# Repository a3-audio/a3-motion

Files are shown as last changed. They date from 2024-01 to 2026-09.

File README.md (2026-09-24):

# A³ Motion

The 4-channel motion sampler: records movement trajectories on a touchscreen
sphere and plays them back in time with the beat, steering per-channel
position on [A³ Core](https://github.com/a3-audio/a3-core) over OSC.

**The device runs on a Raspberry Pi 5.** The Pi carries the touchscreen UI --
[a3-motion-ui](https://github.com/a3-audio/a3-motion-ui), wired in here as the
`ui` submodule -- while the panel's buttons, encoders and pots are handled by
an ESP32-S3 (`firmware/`, a PlatformIO project) over a binary poll frame. The
PCB design is in `hardware/`.

## Setting up a new installation
- flash the latest Raspberry Pi OS Lite image
- resize sd-card space with gparted to maximum size
- boot raspberry pi
- define keyboard layout
- add user aaa and set password
- perform sudo apt update && sudo apt upgrade
- perform sudo apt install lightdm vim i3-wm dmenu x11-xserver-utils git build-essentials cmake libserial-dev gpiod libgpiod-dev
- Sudo raspi-config > Interface Options
  - (+) SSH
  - (+) I2C
- Sudo raspi-config > System-Settings > Hostname
  - a3-motion-v02
- sudo vim /etc/hosts
  - make sure hostname is correct
- sudo groupadd autologin
- sudo usermod -aG autologin aaa
- sudo vim /etc/lightdm/lightdm.conf
```
[Seat:*]
xserver-command=X -nocursor
autologin-user=aaa
autologin-session=i3
```
- sudo systemctl set-default graphical.target
- sudo systemctl enable lightdm
- configure autostart at the end of ~/.config/i3/config
  - remove bar {} block
  - rotate display for portrait orientation
  - rotate mouse input coordinates
  - disable screen saver and screen power management
  - start motion controller ui
```
exec --no-startup-id xrandr -o right
exec --no-startup-id xinput set-prop "wch.cn USB2IIC_CTP_CONTROL" --type=float "Coordinate Transformation Matrix" 0 1 0 -1 0 1 0 0 1

exec --no-startup-id xset s off
exec --no-startup-id xset -dpms

exec sleep 1

exec /usr/bin/bash /home/aaa/a3-system/a3motion/a3MotioncontrollerUI/moc.sh --serial_device /dev/ttyACM0 --server_ip "192.168.43.50" --server_port 9000 --encoder_base_port 1337
```
- configure network: vim /etc/dhcpcd.conf
```
# Example static IP configuration:
interface eth0
static ip_address=192.168.43.52/24
static routers=192.168.43.1
static domain_name_servers=192.168.43.1 8.8.8.8
```
- git clone --recursive https://github.com/a3-audio/a3-motion.git
- build a3-motion-ui
  - see a3motion/ui/readme.md

----------------------------------
- set up kernel config (TODO: what was changed compared to stock installation?)
```
#gpu_mem=64
initramfs initramfs-linux.img followkernel
kernel=kernel8.img
arm_64bit=1
disable_overscan=1
dtparam=krnbt=on

#enable sound
dtparam=audio=on
#hdmi_drive=2

#enable vc4
dtoverlay=vc4-kms-v3d
max_framebuffers=2
disable_splash=1

display_rotate=2
```

## Branching in Git

Work happens on `main`; a version is an annotated tag, set in every A³
repository at once. **The reasoning, and the scheme it replaced, are written
once in the umbrella** — see *Where this fits* below.

## Where this fits

A³ is seven repositories and one system. **The structure, the workflow and the
versioning are described once, in the umbrella:**
[a3-audio/a3-system](https://github.com/a3-audio/a3-system#repositories-and-versioning).

The short of it: work happens on `main`, a version is an annotated tag, and
the same tag name is set in every repository at once — `v03.0` is the first.

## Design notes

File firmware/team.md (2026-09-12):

# A3 Motion – Firmware Team Reference

## Überblick

Die Firmware läuft auf einem **ESP32-S3-DevKitC-1-N16R8** (16 MB Flash, 8 MB OPI PSRAM) unter dem Arduino-Framework via PlatformIO.

Die Kommunikation mit dem Host (z. B. Raspberry Pi oder PC) findet über **USB-CDC** statt – der ESP erscheint dabei als `/dev/ttyACM0` oder `/dev/ttyACM1`. Es werden keine separaten Hardware-UART-Pins belegt. Das Protokoll ist **binär** (Byte-Frames) und ermöglicht Auslesen von Buttons, Encodern, Potis sowie LED-Steuerung.

---

## Projektstruktur

```
firmware/
├── boards/
│   └── esp32-s3-devkitc-1-n16r8.json   Lokale Board-Definition (16 MB/PSRAM + USB-CDC aktiv)
├── include/
│   ├── config.h             GPIO-Pins, Konstanten, LED-Matrix-Definition
│   ├── multiplexer_map.h    Button-/Encoder-/Poti-Mappings (MATRIX_BUTTONS, ENCODERS, POTIS)
│   ├── mux_io.h             MUX-Kanal-Selektion und digitale Lesefunktionen
│   ├── buttons.h            Bounce2-Debounce + 2-Bit-Zustandsverfolgung für alle Buttons
│   ├── encoder.h            Quadratur-Dekodierung, Delta-Puffer, Encoder-Schalter-Debounce
│   ├── potis.h              ADC-Lesefunktionen für alle Potis
│   ├── usart.h              Thin Wrapper um USB-CDC Serial
│   ├── protocol.h           Protokoll-Dispatcher (PING, GET_POTS, GET_ENCODERS, GET_BUTTONS)
│   └── a3_special.h         Easter-Egg-Deklaration
└── src/
    ├── main.cpp             Setup, Loop, Protokoll-Dispatch, Easter-Egg-Trigger
    ├── mux_io.cpp
    ├── buttons.cpp
    ├── encoder.cpp
    ├── potis.cpp
    ├── usart.cpp
    ├── protocol.cpp
    └── a3_special.cpp       A/III LED-Matrix-Animation
```

---

## Abhängigkeiten / Libraries

| Library | Zweck | PlatformIO-Quelle |
|---|---|---|
| Adafruit NeoPixel | LED-Strip-Ansteuerung | `adafruit/Adafruit NeoPixel` |
| **Bounce2** | Button-Debounce (alle Matrix-Buttons und Encoder-Schalter) | `thomasfredericks/Bounce2` |

PlatformIO lädt beide Libraries automatisch beim ersten `pio run`. Kein manuelles Installieren nötig.

---

## Kommunikationsprotokoll

### Verbindungsparameter

| Parameter | Wert |
|---|---|
| Port | `/dev/ttyACM0` |
| Format | **Binär**, byteweise |

Der Port erscheint nach dem Einschalten des Geräts. Mit `ARDUINO_USB_MODE=1` (HWCDC) läuft die Übertragung über den nativen USB-Peripheral des ESP32-S3 (USB Full-Speed, ~12 Mbit/s). Die Baudrate-Einstellung im Host-Treiber ist für HWCDC irrelevant. 450 KB/s+ sind problemlos erreichbar.

### Protokoll-Struktur

- **Request**: immer **1 Byte** (Opcode)
- **Response**: bei Read-Kommandos **1 Byte Opcode-Echo** (Header) + Nutzdaten
- `SET_LED` und `SET_ALL_LEDS` haben **keine** Antwort

### Befehle und Antworten

#### `0x01` PING
```
→ [0x01]
← [0x01]                          (1 Byte)
```

#### `0x02` GET_POTS
Liest alle 4 Potis (direktverdrahtet am ADC, kein MUX).
```
→ [0x02]
← [0x02] [u16 LE] [u16 LE] [u16 LE] [u16 LE]    (9 Byte)
```
- 4 × ADC-Wert 0–4095 als uint16, Little-Endian

#### `0x03` GET_ENCODERS
Liest akkumulierte Rotationsdeltas und Schalter-Zustände. **Puffer wird nach dem Lesen auf 0 zurückgesetzt.**
```
→ [0x03]
← [0x03] (8 × [i16 LE delta] [u8 switchState])   (25 Byte)
```
- `delta`: signed int16 LE, akkumuliert seit letztem Aufruf (positiv = CW)
- `switchState`: 2-Bit-Zustand (s. u.)

#### `0x04` GET_BUTTONS
Liest den 2-Bit-Zustand aller 44 Matrix-Buttons. **Transition-Flags werden nach dem Lesen zurückgesetzt.**
```
→ [0x04]
← [0x04] [11 Byte gepackt]                        (12 Byte)
```
- 44 Buttons × 2 Bit = 88 Bit → 11 Bytes, LSB-first, 4 Buttons pro Byte
- Byte 0: Bits[1:0]=btn0, [3:2]=btn1, [5:4]=btn2, [7:6]=btn3, …
- Reihenfolge entspricht `MATRIX_BUTTONS[]` in `multiplexer_map.h`

#### `0x05` SET_LED
Setzt eine einzelne LED per RGB.
```
→ [0x05] [u8 led_id] [u8 r] [u8 g] [u8 b]         (5 Byte)
```
- keine Response
- `led_id` Bereich: `0..NUMPIXELS-1`

#### `0x06` SET_ALL_LEDS
Setzt alle LEDs auf dieselbe Farbe.
```
→ [0x06] [u8 r] [u8 g] [u8 b]                      (4 Byte)
```
- keine Response

#### `0xFF` ERR — unbekannter Opcode
```
← [0xFF] [echo des empfangenen Bytes]             (2 Byte)
```

### 2-Bit-Zustandscodierung (Buttons und Encoder-Schalter)

| Wert | Bedeutung | Details |
|---|---|---|
| `0`  | Steady pressed  | Button war die ganze Zeit LOW (gedrückt), keine Flanke |
| `1`  | Steady released | Button war HIGH (losgelassen) oder gerade erst HIGH geworden |
| `2`  | Brief release | Button war LOW → kurz HIGH → wieder LOW (kurz losgelassen) |
| `3`  | **CLICK** | Button war HIGH → LOW (Drücken) → HIGH (Loslassen) |

- **bit0** = aktueller Debounce-Pegel (0 = LOW/gedrückt, 1 = HIGH/losgelassen)
- **bit1** = beide Flanken (Drücken und Loslassen) wurden seit letztem Aufruf erkannt

---

## Hardware-Anmerkungen

### MUX-Schema
- **5 Button-MUXe** (MUX 0–4): je 8 Kanäle → 40 Matrix-Buttons
- **4 Extra-Buttons** (BUTTON_00, 10, 09, 19) auf MUX 5 und MUX 8
- **Encoder-B + Schalter** auf MUX 5, 6, 7 und 8
- **Encoder-A** direkt verkabelt (GPIO 5–7, 10–13, 18)
- **Potis** (4×) direkt am ADC (GPIO 3, 4, 16, 17) – kein MUX

### Bounce2 mit MUX
Da Bounce2 intern `digitalRead(pin)` aufruft, wird vor jedem `update()`-Aufruf manuell der korrekte MUX-Kanal gesetzt (`selectMuxChannel()`). Mehrere Bounce2-Objekte können denselben GPIO-Pin teilen, solange der MUX-Kanal unmittelbar vor dem `update()` gesetzt wird.

### USB-CDC-Konfiguration
Die lokale Board-Datei `boards/esp32-s3-devkitc-1-n16r8.json` setzt `-DARDUINO_USB_MODE=1` (Hardware-USB-CDC). Damit mappt `Serial` auf den nativen USB-Peripheral des ESP32-S3 und erscheint als `/dev/ttyACM0` – ohne GPIO-Pins zu belegen.

### LED-Steuerung
Die frühere LED-Toggle-Logik in der Firmware-Loop ist deaktiviert. LEDs werden ausschließlich per Host-Protokoll (`0x05`/`0x06`) gesteuert.

### Laufzeit-/Performance-Strategie
- Input-Scan läuft zyklisch mit festem Intervall (`INPUT_SCAN_INTERVAL_US`) statt mit fixem `delay()` pro Loop.
- Pro Loop werden mehrere eingehende Protokoll-Kommandos innerhalb eines Zeitbudgets verarbeitet (`CMD_PROCESS_BUDGET_US`).
- LED-Updates werden zusammengefasst: `SET_LED`/`SET_ALL_LEDS` markieren nur den Pixelbuffer als geändert; `strip.show()` wird zentral und begrenzt über `protocol_led_flush()` ausgeführt (`LED_SHOW_MIN_INTERVAL_US`).

### Easter Egg
BUTTON_00 und BUTTON_09 gleichzeitig halten → 5 Sekunden lang wechselt die LED-Matrix zwischen `A` und `III` (je 500 ms). Implementiert in `src/a3_special.cpp`.

---

## Build und Upload

```bash
# Firmware bauen
pio run

# Firmware hochladen
pio run -t upload

# Seriellen Monitor öffnen
pio device monitor
# oder direkt:
python3 -m serial.tools.miniterm /dev/ttyACM0 115200

# Hinweis: Nicht parallel zu ui/host.py auf demselben Port öffnen.
```

### Schnelltest des Protokolls
```python
import serial, struct

ser = serial.Serial('/dev/ttyACM0', 2000000, timeout=1)

# PING
ser.write(b'\x01')
print(ser.read(1))          # b'\x01'

# GET_POTS
ser.write(b'\x02')
data = ser.read(9)          # 1 header + 4 × uint16
opcode, v0, v1, v2, v3 = struct.unpack('<BHHHH', data)
print(v0, v1, v2, v3)       # ADC 0..4095

# GET_BUTTONS
ser.write(b'\x04')
data = ser.read(12)         # 1 header + 11 packed bytes
packed = data[1:]
states = [(packed[i // 4] >> ((i % 4) * 2)) & 0x03 for i in range(44)]
print(states)               # list of 0/1/2/3 per button
```

---

## Python-Client (Master-Seite — TODO für das Team)

> **Aufgabe:** Auf dem Master (Raspberry Pi o. ä.) muss ein Python-Skript erstellt werden, das dieselben Protokoll-Opcodes kennt und darüber mit dem ESP kommuniziert. Die unten stehende Beispiel-Klasse kann als Ausgangspunkt dienen — sie muss noch in die Master-Software integriert werden (z. B. in `rpi/`).

Der ESP sendet ausschließlich Antworten auf eingehende Opcodes (kein automatisches Push). Das Protokoll ist **binär** – kein Text, kein ASCII-Parsing.

Benötigte Library: `pyserial` (`pip install pyserial`).

Beispiel-Klasse:
```python
import serial, struct

class A3MotionClient:
    PING         = 0x01
    GET_POTS     = 0x02
    GET_ENCODERS = 0x03
    GET_BUTTONS  = 0x04
    SET_LED      = 0x05
    SET_ALL_LEDS = 0x06

    def __init__(self, port='/dev/ttyACM0'):
        self.ser = serial.Serial(port, 2000000, timeout=0.1)

    def ping(self):
        self.ser.write(bytes([self.PING]))
        return self.ser.read(1) == b'\x01'

    def get_pots(self):
        self.ser.write(bytes([self.GET_POTS]))
        data = self.ser.read(9)
        return struct.unpack_from('<4H', data, 1)  # (v0, v1, v2, v3)

    def get_encoders(self):
        self.ser.write(bytes([self.GET_ENCODERS]))
        data = self.ser.read(25)
        result = []
        for i in range(8):
            delta, = struct.unpack_from('<h', data, 1 + i * 3)
            sw = data[3 + i * 3]
            result.append((delta, sw))
        return result  # [(delta, switchState), ...]

    def get_buttons(self):
        self.ser.write(bytes([self.GET_BUTTONS]))
        data = self.ser.read(12)
        packed = data[1:]
        return [(packed[i // 4] >> ((i % 4) * 2)) & 0x03 for i in range(44)]

    def set_led(self, led_id, r, g, b):
        self.ser.write(bytes([self.SET_LED, led_id & 0xFF, r & 0xFF, g & 0xFF, b & 0xFF]))

    def set_all_leds(self, r, g, b):
        self.ser.write(bytes([self.SET_ALL_LEDS, r & 0xFF, g & 0xFF, b & 0xFF]))
```

---

## Dateiänderungen kurz erklärt

| Datei | Änderung |
|---|---|
| `boards/esp32-s3-devkitc-1-n16r8.json` | `ARDUINO_USB_MODE=1` gesetzt (USB-CDC aktiv); `ARDUINO_USB_CDC_ON_BOOT` entfernt |
| `platformio.ini` | `thomasfredericks/Bounce2` zu `lib_deps` hinzugefügt |
| `src/main.cpp` | Komplett refactored: nur noch Setup, Loop, LED-Toggle und Easter-Egg-Trigger |
| `include/a3_special.h` | Nutzt jetzt `mux_io.h` statt eigenem `extern`-Deklaration |
| `include/mux_io.h` + `src/mux_io.cpp` | Neu: MUX-Hilfsfunktionen ausgelagert |
| `include/buttons.h` + `src/buttons.cpp` | Neu: Bounce2 + 2-Bit-Zustand für alle 44 Matrix-Buttons |
| `include/encoder.h` + `src/encoder.cpp` | Neu: Quadratur-Dekodierung, Delta-Puffer, Schalter-Debounce |
| `include/potis.h` + `src/potis.cpp` | Neu: ADC-Lesefunktionen |
| `src/usart.cpp` / `include/usart.h` | Neu binär: `usart_readByte()` + `usart_write(data, len)`; kein readline/writeln mehr |
| `src/protocol.cpp` / `include/protocol.h` | Neu binär: 1-Byte-Opcodes, packed binary responses; kein snprintf/strcmp |

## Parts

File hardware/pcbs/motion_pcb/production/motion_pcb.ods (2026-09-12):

Reference | Value | Mouser | Datasheet | Footprint | Qty | DNP | Description
C1 | 10v/1mF | 667-EEE-1AA102P | ~ | Capacitor_SMD:CP_Elec_10x10 | 1 |  | Polarized capacitor
C2,C3,C4,C5,C6,C7,C8,C9,C10,C11,C12,C13,C14,C15,C16,C17,C18,C19,C20,C21,C22,C23,C26,C27 | 100nF |  | ~ | Capacitor_SMD:C_1206_3216Metric_Pad1.33x1.80mm_HandSolder | 24 | DNP | Unpolarized capacitor
C24,C25,C28,C29,C30,C31,C32,C33,C35 | 100nF |  | ~ | Capacitor_SMD:C_1206_3216Metric_Pad1.33x1.80mm_HandSolder | 9 |  | Unpolarized capacitor
D1,D2,D3,D4,D5,D6,D7,D8,D9,D10,D11,D12,D13,D14,D15,D16,D17,D18,D19,D20,D21,D22,D23,D24,D25,D26,D27,D28,D29,D30,D31,D32,D33,D34,D35,D36,D37,D38,D39,D40,D41,D42,D43,D44 | WS2812B-2020 |  | https://cdn-shop.adafruit.com/product-files/4684/4684_WS2812B-2020_V1.3_EN.pdf | 3dAudioFoot:A3_CherryMxHybrid_WS2812Led2020 | 44 |  | RGB LED with integrated controller, 2.0 x 2.0 mm, 12 mA
IC1,U1,U5,U9,U13,U17,U21,U25,U29,U33,U37,U41,U49 | ~ |  |  | 3dAudioFoot:A3_ENC_POT_mix,3dAudioFoot:ESP32-S3-DevKitC-1 | 13
Q1 | BSS138 | 512-BSS138 | https://www.onsemi.com/pub/Collateral/BSS138-D.PDF | Package_TO_SOT_SMD:SOT-23 | 1 | DNP | 50V Vds, 0.22A Id, N-Channel MOSFET, SOT-23
R1,R2,R3,R4,R5,R6,R12,R13,R14,R15,R16,R22,R23,R24,R25,R26,R27,R38,R39,R45,R46,R52,R53,R54,R60,R61,R62,R68,R69,R70,R71,R77,R78,R79,R80,R81,R82,R83,R84,R85,R86,R87,R89,R100 | 10k |  | ~ | Resistor_SMD:R_1206_3216Metric_Pad1.30x1.75mm_HandSolder | 44 |  | Resistor
R7,R17,R28,R33,R40,R47,R55,R63,R72,R88,R94,R97,R106 | 10k |  | ~ | Resistor_SMD:R_1206_3216Metric_Pad1.30x1.75mm_HandSolder | 13 | DNP | Resistor
R8,R9,R18,R19,R29,R30,R34,R35,R41,R42,R48,R49,R56,R57,R64,R65,R73,R74,R90,R91,R102,R103,R107,R108 | 10K |  | ~ | Resistor_SMD:R_1206_3216Metric_Pad1.30x1.75mm_HandSolder | 24 | DNP | Resistor
R10,R11,R20,R21,R31,R32,R36,R37,R43,R44,R50,R51,R58,R59,R66,R67,R75,R76,R92,R93,R95,R104,R105,R109,R110 | 1k |  | ~ | Resistor_SMD:R_1206_3216Metric_Pad1.30x1.75mm_HandSolder | 25 | DNP | Resistor
R99 | 0 |  | ~ | Resistor_SMD:R_1206_3216Metric_Pad1.30x1.75mm_HandSolder | 1 | DNP | Resistor
U42 | SN74LVC1T45DBV | 595-SN74LVC1T45DBVR | http://www.ti.com/lit/ds/symlink/sn74lvc1t45.pdf | Package_TO_SOT_SMD:SOT-23-6 | 1 | DNP | Single-Bit Dual-Supply Bus Transceiver With Configurable Voltage Translation and 3-State Outputs, SOT-23-6
U43,U47,U48,U53,U54,U55,U56,U57,U59 | 74HC4051 | 771-74HC4051D-T | http://www.ti.com/lit/ds/symlink/cd74hc4051.pdf | Package_SO:SOIC-16_3.9x9.9mm_P1.27mm | 9 |  | 8-channel analog multiplexer/demultiplexer, DIP-16/SOIC-16/TSSOP-16
DNP!!! heist nicht bestücken ein Encoeder benötigt 3x 10k 1206 R, 2x 1k 1206R und 2x 1206 100nF

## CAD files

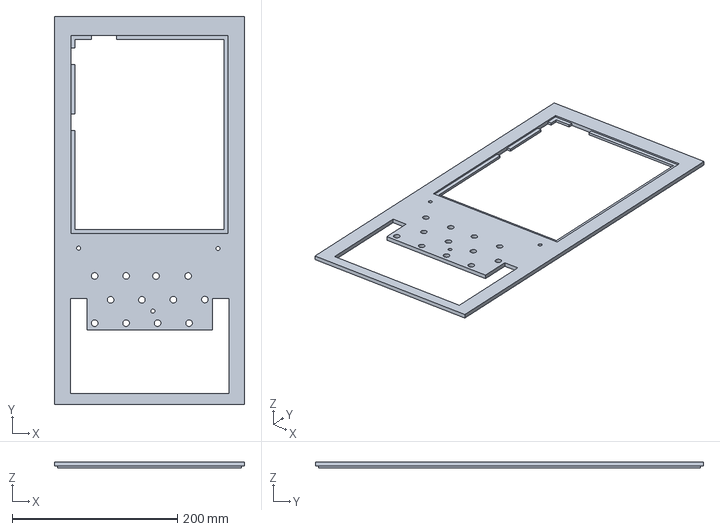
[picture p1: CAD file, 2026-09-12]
hardware/housing/freecad/housing_v3.FCStd
230.0 x 470.0 x 7.00 mm

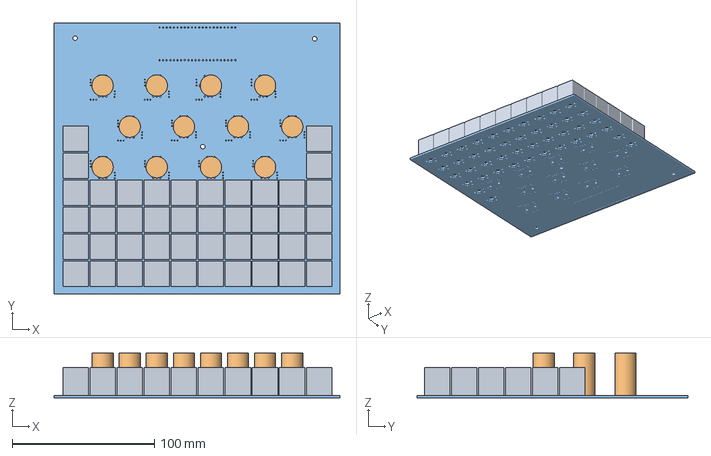
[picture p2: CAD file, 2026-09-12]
hardware/housing/freecad/housing_v3-controller.3mf
201.2 x 190.3 x 31.6 mm

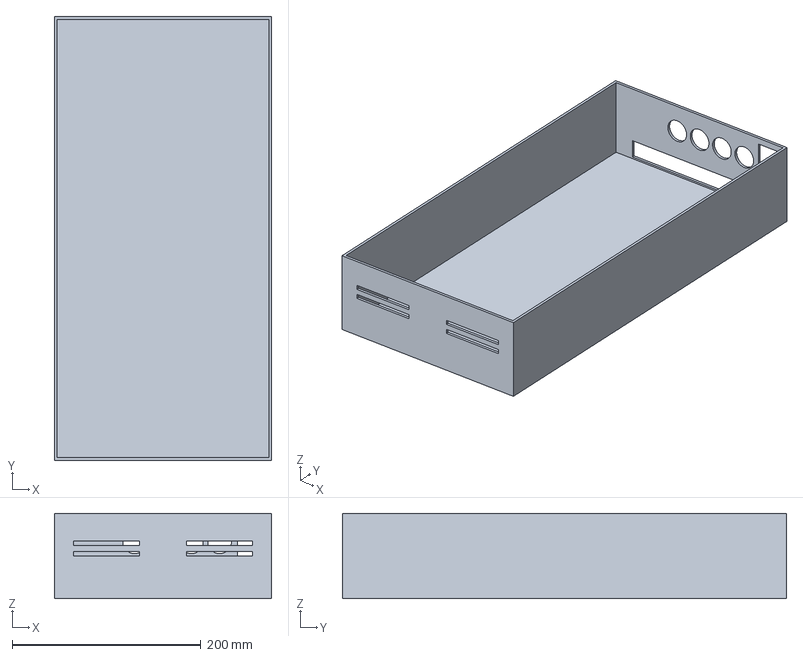
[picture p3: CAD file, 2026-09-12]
hardware/housing/freecad/production/housing_v3-motion_box.3mf
230.0 x 470.0 x 90.0 mm

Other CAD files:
hardware/housing/freecad/production/housing_v3-motion_pcbfaceplate.3mf
hardware/housing/freecad/production/housing_v3-motion_pcbCut008.stl
hardware/housing/freecad/production/housing_v3-motion_pcbfaceplate.stl

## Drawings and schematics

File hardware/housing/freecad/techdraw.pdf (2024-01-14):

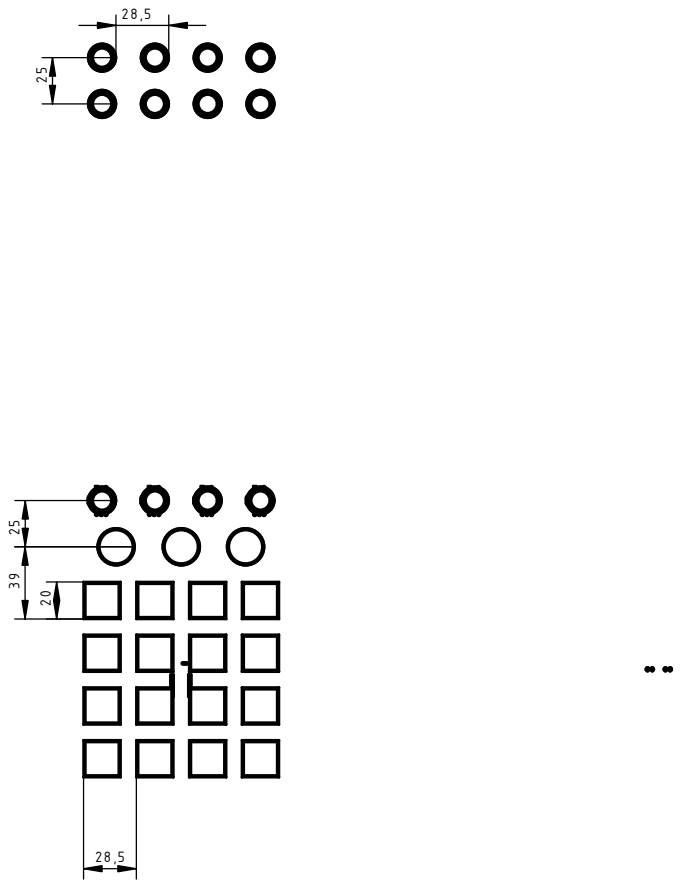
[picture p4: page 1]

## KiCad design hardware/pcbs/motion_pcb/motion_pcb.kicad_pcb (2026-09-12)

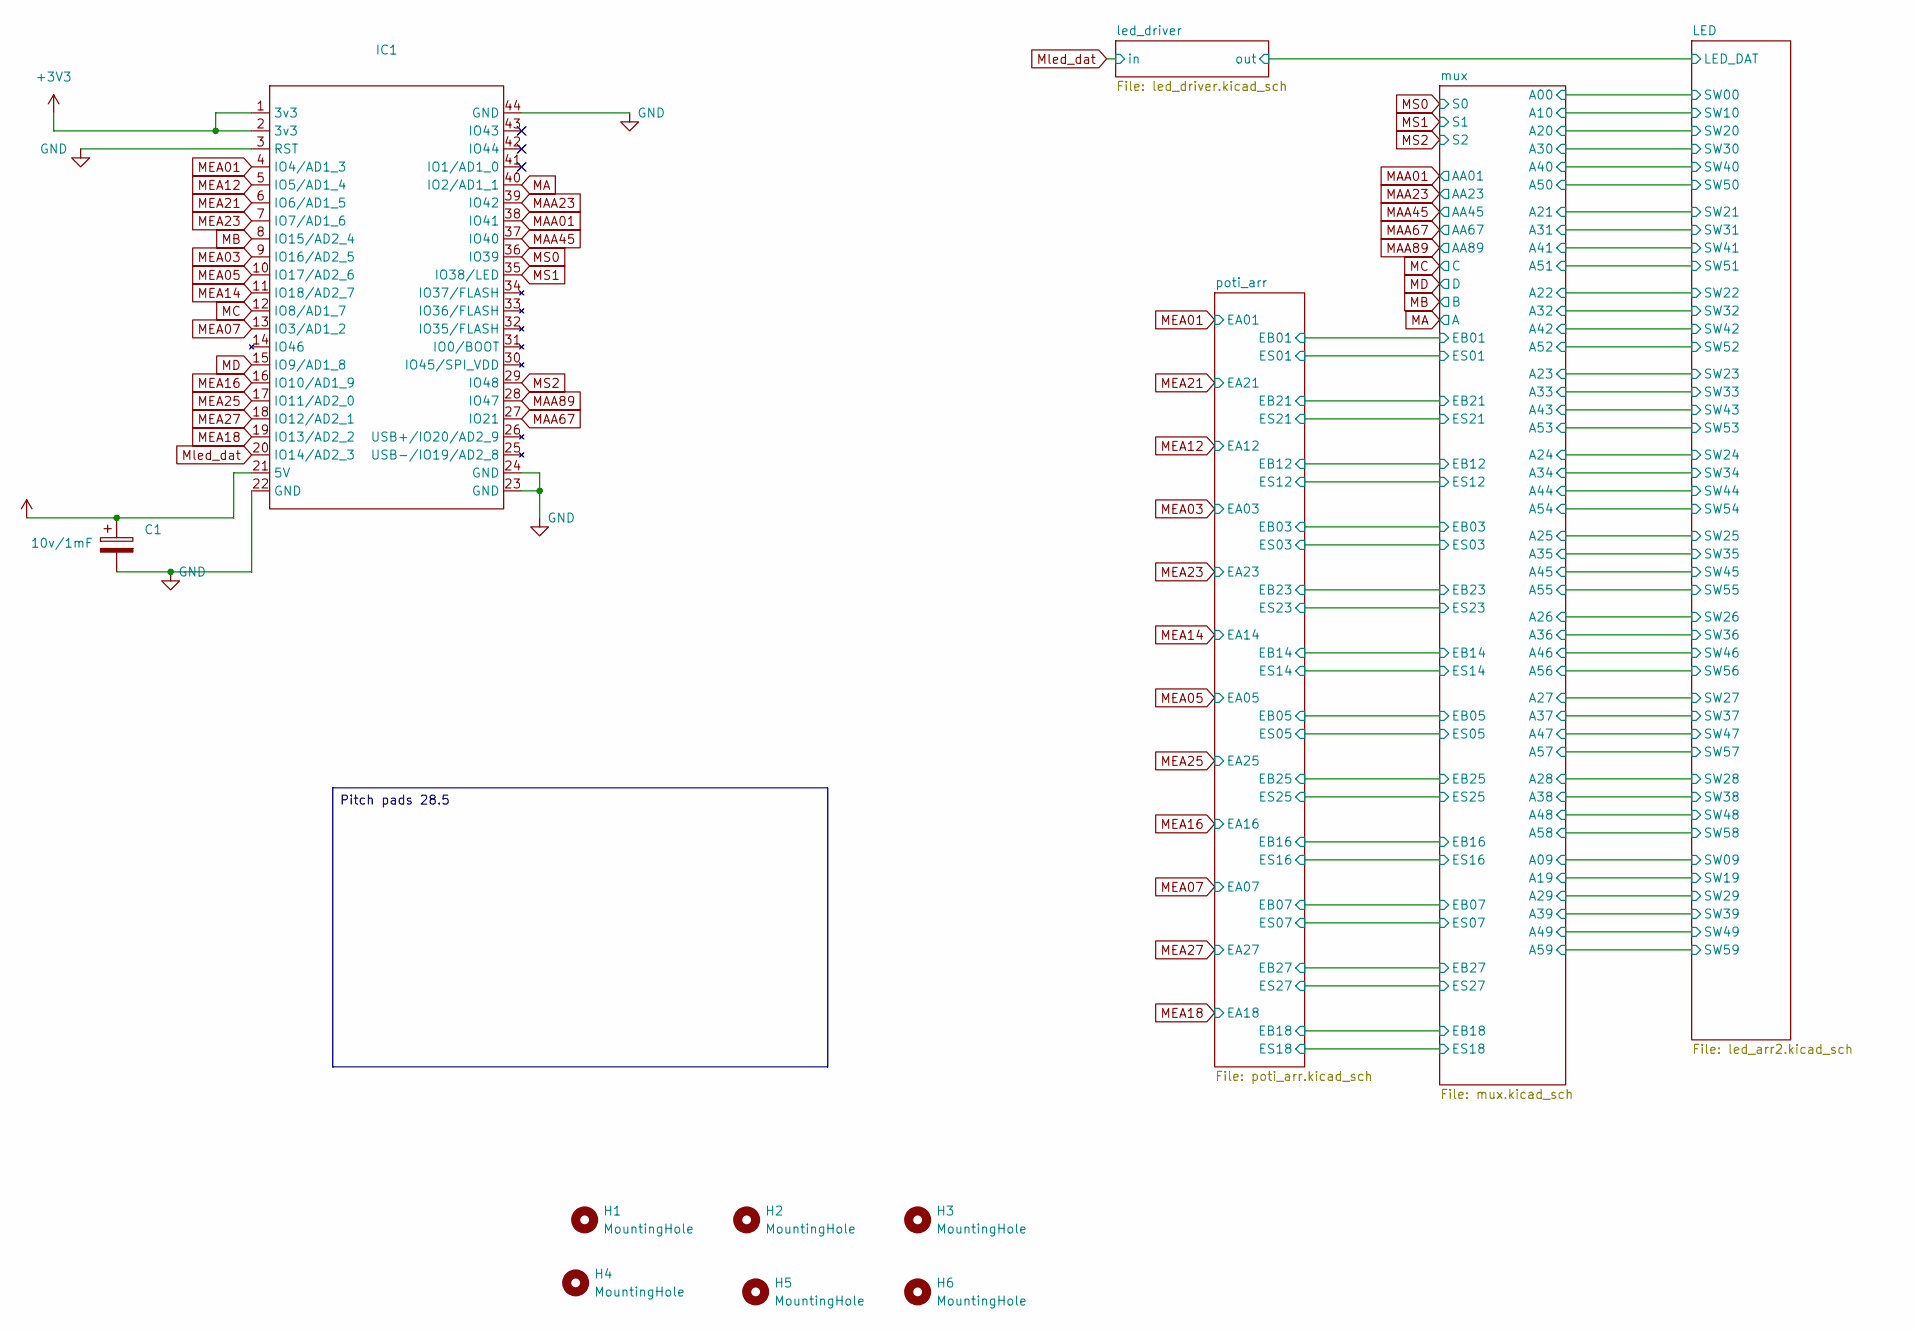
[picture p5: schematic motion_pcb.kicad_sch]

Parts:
C1: 10v/1mF; CP_Elec_10x10
H1, H2, H3, H4, H5, H6: MountingHole; MountingHole_3.2mm_M3
IC1: ESP32-S3-DevKitC-1

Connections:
+3V3: IC1.1 (3v3), IC1.2 (3v3); also elsewhere on the board
+5V: C1.1, IC1.21 (5V); also elsewhere on the board
GND: C1.2, IC1.3 (RST), IC1.22 (GND), IC1.23 (GND), IC1.24 (GND), IC1.44 (GND); also elsewhere on the board
MA: IC1.40 (IO2/AD1_1); also elsewhere on the board
MAA01: IC1.38 (IO41); also elsewhere on the board
MAA23: IC1.39 (IO42); also elsewhere on the board
MAA45: IC1.37 (IO40); also elsewhere on the board
MAA67: IC1.27 (IO21); also elsewhere on the board
MAA89: IC1.28 (IO47); also elsewhere on the board
MB: IC1.8 (IO15/AD2_4); also elsewhere on the board
MC: IC1.12 (IO8/AD1_7); also elsewhere on the board
MD: IC1.15 (IO9/AD1_8); also elsewhere on the board
MEA01: IC1.4 (IO4/AD1_3); also elsewhere on the board
MEA03: IC1.9 (IO16/AD2_5); also elsewhere on the board
MEA05: IC1.10 (IO17/AD2_6); also elsewhere on the board
MEA07: IC1.13 (IO3/AD1_2); also elsewhere on the board
MEA12: IC1.5 (IO5/AD1_4); also elsewhere on the board
MEA14: IC1.11 (IO18/AD2_7); also elsewhere on the board
MEA16: IC1.16 (IO10/AD1_9); also elsewhere on the board
MEA18: IC1.19 (IO13/AD2_2); also elsewhere on the board
MEA21: IC1.6 (IO6/AD1_5); also elsewhere on the board
MEA23: IC1.7 (IO7/AD1_6); also elsewhere on the board
MEA25: IC1.17 (IO11/AD2_0); also elsewhere on the board
MEA27: IC1.18 (IO12/AD2_1); also elsewhere on the board
MS0: IC1.36 (IO39); also elsewhere on the board
MS1: IC1.35 (IO38/LED); also elsewhere on the board
MS2: IC1.29 (IO48); also elsewhere on the board
led_dat: IC1.20 (IO14/AD2_3); also elsewhere on the board

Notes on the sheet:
Pitch pads 28.5

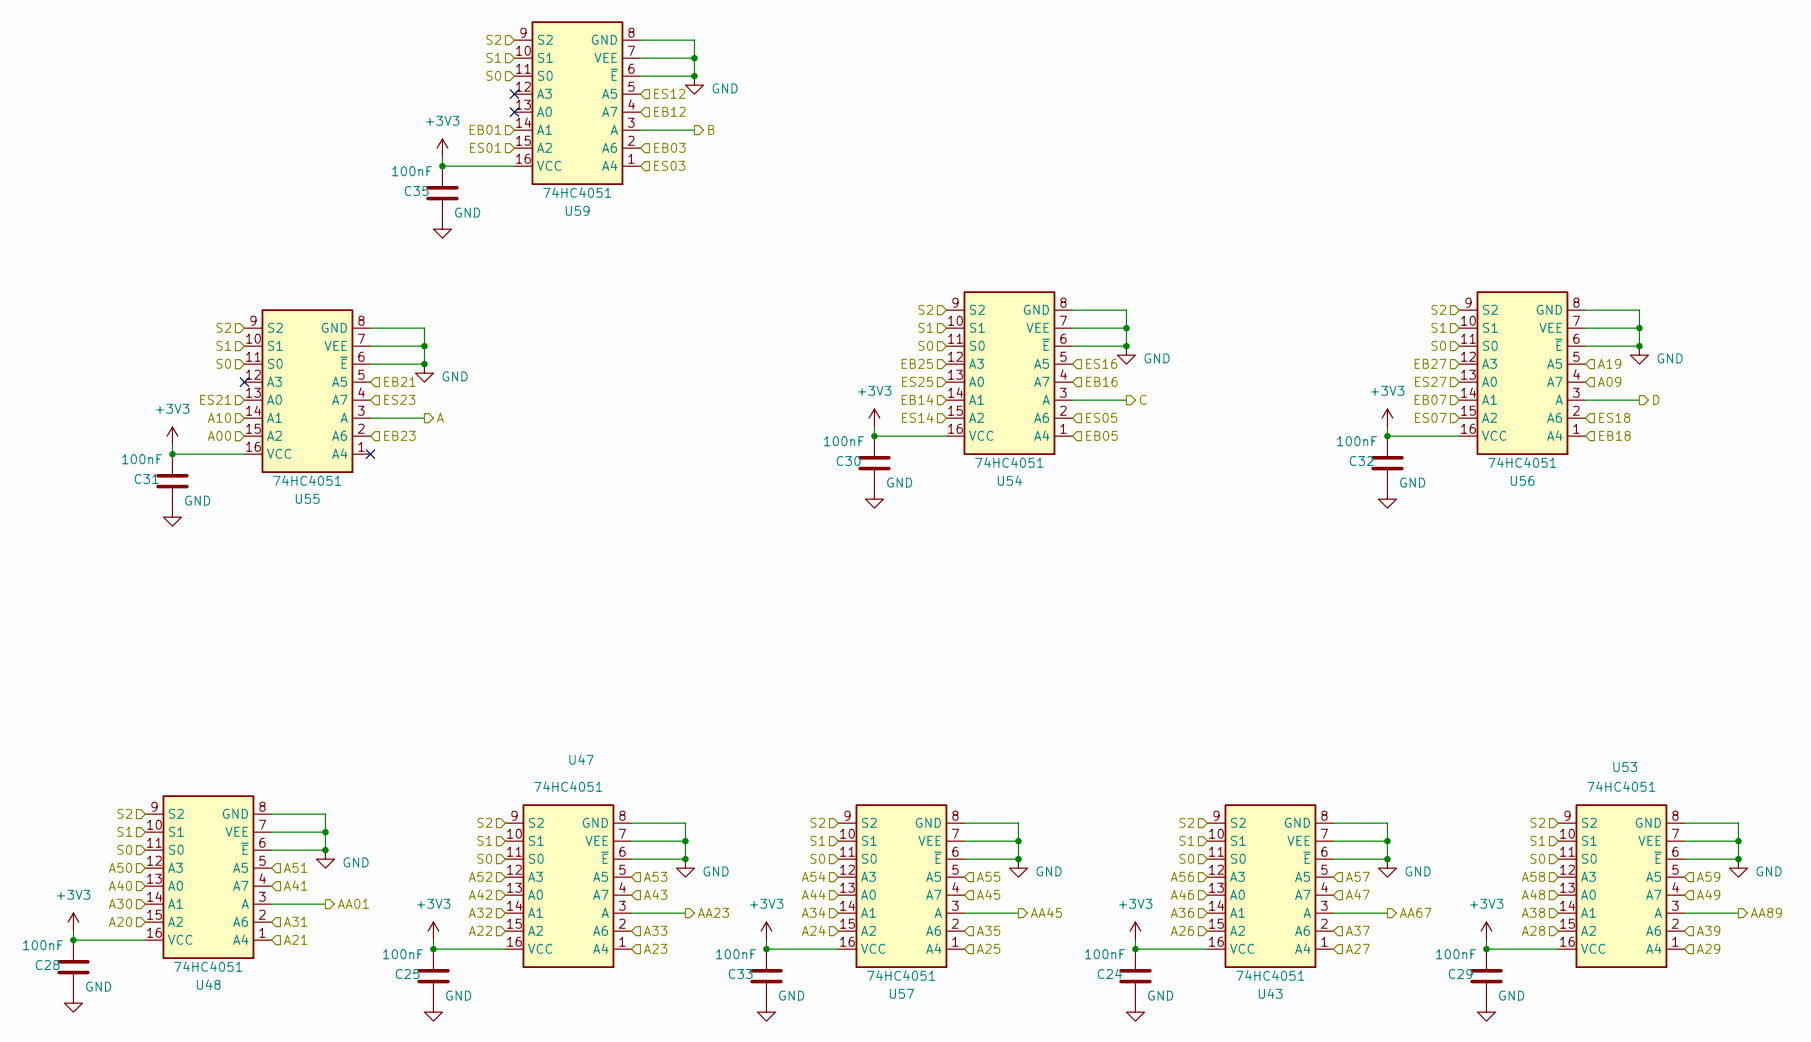
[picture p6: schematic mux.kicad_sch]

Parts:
C24, C25, C28, C29, C30, C31, C32, C33, C35: 100nF; C_1206_3216Metric_Pad1.33x1.80mm_HandSolder
U43, U47, U48, U53, U54, U55, U56, U57, U59: 74HC4051; SOIC-16_3.9x9.9mm_P1.27mm

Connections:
+3V3: C24.1, C25.1, C28.1, C29.1, C30.1, C31.1, C32.1, C33.1, C35.1, U43.16 (VCC), U47.16 (VCC), U48.16 (VCC), U53.16 (VCC), U54.16 (VCC), U55.16 (VCC), U56.16 (VCC), U57.16 (VCC), U59.16 (VCC); also elsewhere on the board
/LED/SW00: U55.15 (A2); also elsewhere on the board
/LED/SW09: U56.4 (A7); also elsewhere on the board
/LED/SW10: U55.14 (A1); also elsewhere on the board
/LED/SW19: U56.5 (A5); also elsewhere on the board
/LED/SW20: U48.15 (A2); also elsewhere on the board
/LED/SW21: U48.1 (A4); also elsewhere on the board
/LED/SW22: U47.15 (A2); also elsewhere on the board
/LED/SW23: U47.1 (A4); also elsewhere on the board
/LED/SW24: U57.15 (A2); also elsewhere on the board
/LED/SW25: U57.1 (A4); also elsewhere on the board
/LED/SW26: U43.15 (A2); also elsewhere on the board
/LED/SW27: U43.1 (A4); also elsewhere on the board
/LED/SW28: U53.15 (A2); also elsewhere on the board
/LED/SW29: U53.1 (A4); also elsewhere on the board
/LED/SW30: U48.14 (A1); also elsewhere on the board
/LED/SW31: U48.2 (A6); also elsewhere on the board
/LED/SW32: U47.14 (A1); also elsewhere on the board
/LED/SW33: U47.2 (A6); also elsewhere on the board
/LED/SW34: U57.14 (A1); also elsewhere on the board
/LED/SW35: U57.2 (A6); also elsewhere on the board
/LED/SW36: U43.14 (A1); also elsewhere on the board
/LED/SW37: U43.2 (A6); also elsewhere on the board
/LED/SW38: U53.14 (A1); also elsewhere on the board
/LED/SW39: U53.2 (A6); also elsewhere on the board
/LED/SW40: U48.13 (A0); also elsewhere on the board
/LED/SW41: U48.4 (A7); also elsewhere on the board
/LED/SW42: U47.13 (A0); also elsewhere on the board
/LED/SW43: U47.4 (A7); also elsewhere on the board
/LED/SW44: U57.13 (A0); also elsewhere on the board
/LED/SW45: U57.4 (A7); also elsewhere on the board
/LED/SW46: U43.13 (A0); also elsewhere on the board
/LED/SW47: U43.4 (A7); also elsewhere on the board
/LED/SW48: U53.13 (A0); also elsewhere on the board
/LED/SW49: U53.4 (A7); also elsewhere on the board
/LED/SW50: U48.12 (A3); also elsewhere on the board
/LED/SW51: U48.5 (A5); also elsewhere on the board
/LED/SW52: U47.12 (A3); also elsewhere on the board
/LED/SW53: U47.5 (A5); also elsewhere on the board
/LED/SW54: U57.12 (A3); also elsewhere on the board
/LED/SW55: U57.5 (A5); also elsewhere on the board
/LED/SW56: U43.12 (A3); also elsewhere on the board
/LED/SW57: U43.5 (A5); also elsewhere on the board
/LED/SW58: U53.12 (A3); also elsewhere on the board
/LED/SW59: U53.5 (A5); also elsewhere on the board
/mux/EB01: U59.14 (A1); also elsewhere on the board
/mux/EB03: U59.2 (A6); also elsewhere on the board
/mux/EB05: U54.1 (A4); also elsewhere on the board
/mux/EB07: U56.14 (A1); also elsewhere on the board
/mux/EB12: U59.4 (A7); also elsewhere on the board
/mux/EB14: U54.14 (A1); also elsewhere on the board
/mux/EB16: U54.4 (A7); also elsewhere on the board
/mux/EB18: U56.1 (A4); also elsewhere on the board
/mux/EB21: U55.5 (A5); also elsewhere on the board
/mux/EB23: U55.2 (A6); also elsewhere on the board
/mux/EB25: U54.12 (A3); also elsewhere on the board
/mux/EB27: U56.12 (A3); also elsewhere on the board
/mux/ES01: U59.15 (A2); also elsewhere on the board
/mux/ES03: U59.1 (A4); also elsewhere on the board
/mux/ES05: U54.2 (A6); also elsewhere on the board
/mux/ES07: U56.15 (A2); also elsewhere on the board
/mux/ES12: U59.5 (A5); also elsewhere on the board
/mux/ES14: U54.15 (A2); also elsewhere on the board
/mux/ES16: U54.5 (A5); also elsewhere on the board
/mux/ES18: U56.2 (A6); also elsewhere on the board
/mux/ES21: U55.13 (A0); also elsewhere on the board
/mux/ES23: U55.4 (A7); also elsewhere on the board
/mux/ES25: U54.13 (A0); also elsewhere on the board
/mux/ES27: U56.13 (A0); also elsewhere on the board
GND: C24.2, C25.2, C28.2, C29.2, C30.2, C31.2, C32.2, C33.2, C35.2, U43.6 (~E), U43.7 (VEE), U43.8 (GND), U47.6 (~E), U47.7 (VEE), U47.8 (GND), U48.6 (~E), U48.7 (VEE), U48.8 (GND), U53.6 (~E), U53.7 (VEE), U53.8 (GND), U54.6 (~E), U54.7 (VEE), U54.8 (GND), U55.6 (~E), U55.7 (VEE), U55.8 (GND), U56.6 (~E), U56.7 (VEE), U56.8 (GND), U57.6 (~E), U57.7 (VEE), U57.8 (GND), U59.6 (~E), U59.7 (VEE), U59.8 (GND); also elsewhere on the board
MA: U55.3 (A); also elsewhere on the board
MAA01: U48.3 (A); also elsewhere on the board
MAA23: U47.3 (A); also elsewhere on the board
MAA45: U57.3 (A); also elsewhere on the board
MAA67: U43.3 (A); also elsewhere on the board
MAA89: U53.3 (A); also elsewhere on the board
MB: U59.3 (A); also elsewhere on the board
MC: U54.3 (A); also elsewhere on the board
MD: U56.3 (A); also elsewhere on the board
MS0: U43.11 (S0), U47.11 (S0), U48.11 (S0), U53.11 (S0), U54.11 (S0), U55.11 (S0), U56.11 (S0), U57.11 (S0), U59.11 (S0); also elsewhere on the board
MS1: U43.10 (S1), U47.10 (S1), U48.10 (S1), U53.10 (S1), U54.10 (S1), U55.10 (S1), U56.10 (S1), U57.10 (S1), U59.10 (S1); also elsewhere on the board
MS2: U43.9 (S2), U47.9 (S2), U48.9 (S2), U53.9 (S2), U54.9 (S2), U55.9 (S2), U56.9 (S2), U57.9 (S2), U59.9 (S2); also elsewhere on the board

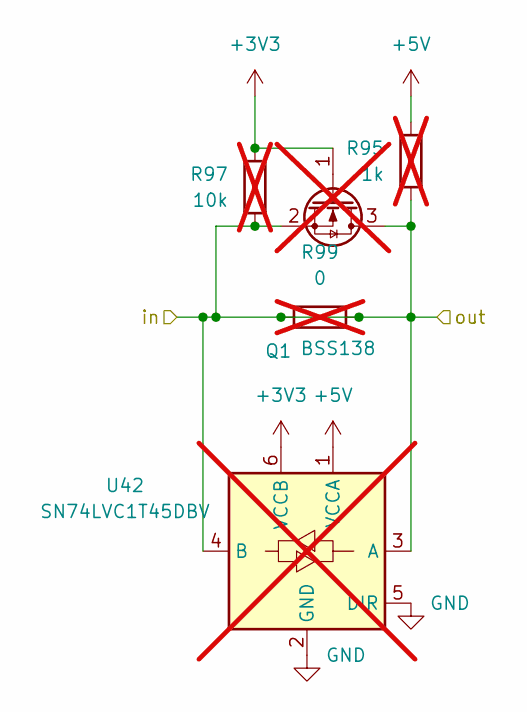
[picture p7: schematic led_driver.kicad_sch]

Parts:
Q1: BSS138; SOT-23; not fitted
R95: 1k; R_1206_3216Metric_Pad1.30x1.75mm_HandSolder; not fitted
R97: 10k; R_1206_3216Metric_Pad1.30x1.75mm_HandSolder; not fitted
R99: 0; R_1206_3216Metric_Pad1.30x1.75mm_HandSolder; not fitted
U42: SN74LVC1T45DBV; SOT-23-6; not fitted

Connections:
+3V3: Q1.1 (G), R97.1, U42.6 (VCCB); also elsewhere on the board
+5V: R95.1, U42.1 (VCCA); also elsewhere on the board
GND: U42.2 (GND), U42.5 (DIR); also elsewhere on the board
led_dat: Q1.2 (S), Q1.3 (D), R95.2, R97.2, R99.1, R99.2, U42.3 (A), U42.4 (B); also elsewhere on the board

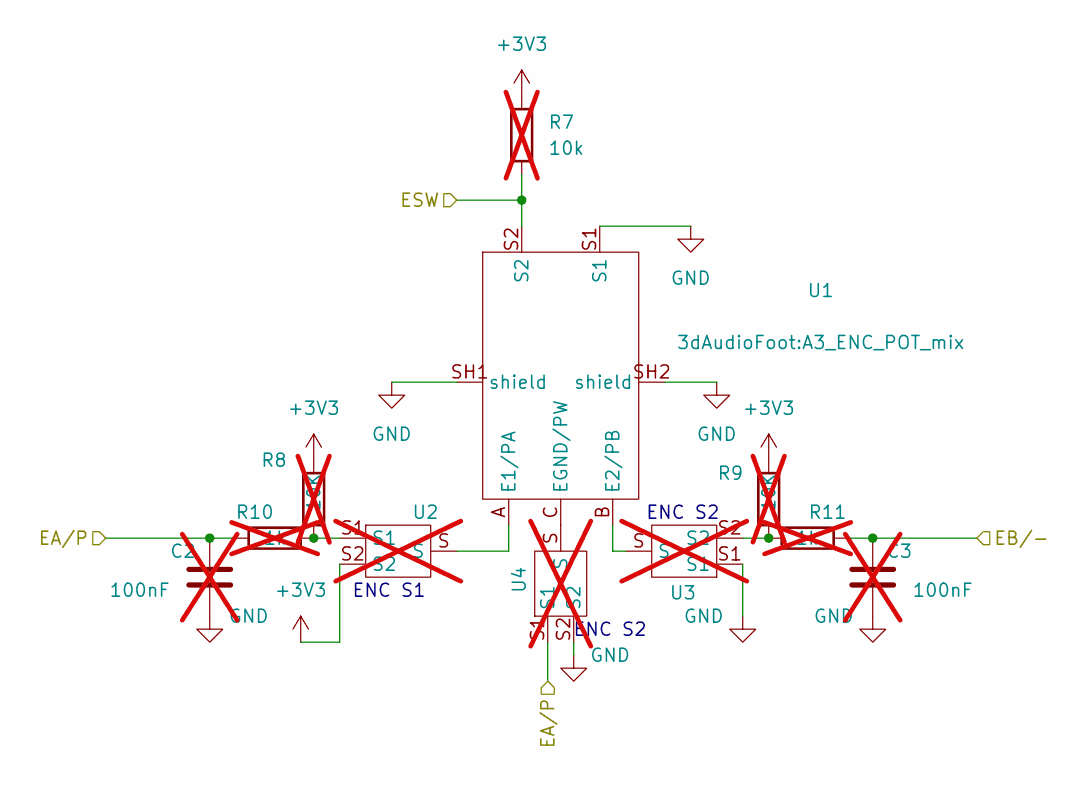
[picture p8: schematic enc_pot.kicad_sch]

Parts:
C2, C3: 100nF; C_1206_3216Metric_Pad1.33x1.80mm_HandSolder; not fitted
R7: 10k; R_1206_3216Metric_Pad1.30x1.75mm_HandSolder; not fitted
R8, R9: 10K; R_1206_3216Metric_Pad1.30x1.75mm_HandSolder; not fitted
R10, R11: 1k; R_1206_3216Metric_Pad1.30x1.75mm_HandSolder; not fitted
U1: A3_ENC_POT_mix
U2, U3, U4: a3_jumper_fix; not fitted

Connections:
+3V3: R7.2, R8.1, R9.1, U2.S2; also elsewhere on the board
/mux/EB21: C3.1, R11.1; also elsewhere on the board
/mux/ES21: R7.1, U1.S2; also elsewhere on the board
GND: C2.2, C3.2, U1.S1, U1.SH1 (shield), U1.SH2 (shield), U3.S1, U4.S2; also elsewhere on the board
MEA21: C2.1, R10.1, U4.S1; also elsewhere on the board
unnamed: R8.2, R10.2, U2.S1
unnamed: R9.2, R11.2, U3.S2
unnamed: U1.A (E1/PA), U2.S
unnamed: U1.B (E2/PB), U3.S
unnamed: U1.C (EGND/PW), U4.S

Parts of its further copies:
C4, C5, C6, C7, C8, C9, C10, C11, C12, C13, C14, C15, C16, C17, C18, C19, C20, C21, C22, C23, C26, C27: 100nF; C_1206_3216Metric_Pad1.33x1.80mm_HandSolder; not fitted
R17, R28, R33, R40, R47, R55, R63, R72, R88, R94, R106: 10k; R_1206_3216Metric_Pad1.30x1.75mm_HandSolder; not fitted
R18, R19, R29, R30, R34, R35, R41, R42, R48, R49, R56, R57, R64, R65, R73, R74, R90, R91, R102, R103, R107, R108: 10K; R_1206_3216Metric_Pad1.30x1.75mm_HandSolder; not fitted
R20, R21, R31, R32, R36, R37, R43, R44, R50, R51, R58, R59, R66, R67, R75, R76, R92, R93, R104, R105, R109, R110: 1k; R_1206_3216Metric_Pad1.30x1.75mm_HandSolder; not fitted
U5, U9, U13, U17, U21, U25, U29, U33, U37, U41, U49: A3_ENC_POT_mix
U6, U7, U8, U10, U11, U12, U14, U15, U16, U18, U19, U20, U22, U23, U24, U26, U27, U28, U30, U31, U32, U34, U35, U36, U38, U39, U40, U44, U45, U46, U50, U51, U52: a3_jumper_fix; not fitted

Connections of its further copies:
+3V3: R17.2, R18.1, R19.1, R28.2, R29.1, R30.1, R33.2, R34.1, R35.1, R40.2, R41.1, R42.1, R47.2, R48.1, R49.1, R55.2, R56.1, R57.1, R63.2, R64.1, R65.1, R72.2, R73.1, R74.1, R88.2, R90.1, R91.1, R94.2, R102.1, R103.1, R106.2, R107.1, R108.1, U6.S2, U10.S2, U14.S2, U18.S2, U22.S2, U26.S2, U30.S2, U34.S2, U38.S2, U44.S2, U50.S2; also elsewhere on the board
/mux/EB01: C11.1, R44.1; also elsewhere on the board
/mux/EB03: C7.1, R32.1; also elsewhere on the board
/mux/EB05: C21.1, R93.1; also elsewhere on the board
/mux/EB07: C15.1, R59.1; also elsewhere on the board
/mux/EB12: C5.1, R21.1; also elsewhere on the board
/mux/EB14: C13.1, R51.1; also elsewhere on the board
/mux/EB16: C19.1, R76.1; also elsewhere on the board
/mux/EB18: C27.1, R110.1; also elsewhere on the board
/mux/EB23: C9.1, R37.1; also elsewhere on the board
/mux/EB25: C23.1, R105.1; also elsewhere on the board
/mux/EB27: C17.1, R67.1; also elsewhere on the board
/mux/ES01: R40.1, U17.S2; also elsewhere on the board
/mux/ES03: R28.1, U9.S2; also elsewhere on the board
/mux/ES05: R88.1, U37.S2; also elsewhere on the board
/mux/ES07: R55.1, U25.S2; also elsewhere on the board
/mux/ES12: R17.1, U5.S2; also elsewhere on the board
/mux/ES14: R47.1, U21.S2; also elsewhere on the board
/mux/ES16: R72.1, U33.S2; also elsewhere on the board
/mux/ES18: R106.1, U49.S2; also elsewhere on the board
/mux/ES23: R33.1, U13.S2; also elsewhere on the board
/mux/ES25: R94.1, U41.S2; also elsewhere on the board
/mux/ES27: R63.1, U29.S2; also elsewhere on the board
GND: C4.2, C5.2, C6.2, C7.2, C8.2, C9.2, C10.2, C11.2, C12.2, C13.2, C14.2, C15.2, C16.2, C17.2, C18.2, C19.2, C20.2, C21.2, C22.2, C23.2, C26.2, C27.2, U5.S1, U5.SH1 (shield), U5.SH2 (shield), U7.S1, U8.S2, U9.S1, U9.SH1 (shield), U9.SH2 (shield), U11.S1, U12.S2, U13.S1, U13.SH1 (shield), U13.SH2 (shield), U15.S1, U16.S2, U17.S1, U17.SH1 (shield), U17.SH2 (shield), U19.S1, U20.S2, U21.S1, U21.SH1 (shield), U21.SH2 (shield), U23.S1, U24.S2, U25.S1, U25.SH1 (shield), U25.SH2 (shield), U27.S1, U28.S2, U29.S1, U29.SH1 (shield), U29.SH2 (shield), U31.S1, U32.S2, U33.S1, U33.SH1 (shield), U33.SH2 (shield), U35.S1, U36.S2, U37.S1, U37.SH1 (shield), U37.SH2 (shield), U39.S1, U40.S2, U41.S1, U41.SH1 (shield), U41.SH2 (shield), U45.S1, U46.S2, U49.S1, U49.SH1 (shield), U49.SH2 (shield), U51.S1, U52.S2; also elsewhere on the board
MEA01: C10.1, R43.1, U20.S1; also elsewhere on the board
MEA03: C6.1, R31.1, U12.S1; also elsewhere on the board
MEA05: C20.1, R92.1, U40.S1; also elsewhere on the board
MEA07: C14.1, R58.1, U28.S1; also elsewhere on the board
MEA12: C4.1, R20.1, U8.S1; also elsewhere on the board
MEA14: C12.1, R50.1, U24.S1; also elsewhere on the board
MEA16: C18.1, R75.1, U36.S1; also elsewhere on the board
MEA18: C26.1, R109.1, U52.S1; also elsewhere on the board
MEA23: C8.1, R36.1, U16.S1; also elsewhere on the board
MEA25: C22.1, R104.1, U46.S1; also elsewhere on the board
MEA27: C16.1, R66.1, U32.S1; also elsewhere on the board
unnamed: R18.2, R20.2, U6.S1
unnamed: R19.2, R21.2, U7.S2
unnamed: R29.2, R31.2, U10.S1
unnamed: R30.2, R32.2, U11.S2
unnamed: R34.2, R36.2, U14.S1
unnamed: R35.2, R37.2, U15.S2
unnamed: R41.2, R43.2, U18.S1
unnamed: R42.2, R44.2, U19.S2
unnamed: R48.2, R50.2, U22.S1
unnamed: R49.2, R51.2, U23.S2
unnamed: R56.2, R58.2, U26.S1
unnamed: R57.2, R59.2, U27.S2
unnamed: R64.2, R66.2, U30.S1
unnamed: R65.2, R67.2, U31.S2
unnamed: R73.2, R75.2, U34.S1
unnamed: R74.2, R76.2, U35.S2
unnamed: R90.2, R92.2, U38.S1
unnamed: R91.2, R93.2, U39.S2
unnamed: R102.2, R104.2, U44.S1
unnamed: R103.2, R105.2, U45.S2
unnamed: R107.2, R109.2, U50.S1
unnamed: R108.2, R110.2, U51.S2
unnamed: U5.A (E1/PA), U6.S
unnamed: U5.B (E2/PB), U7.S
unnamed: U5.C (EGND/PW), U8.S
unnamed: U9.A (E1/PA), U10.S
unnamed: U9.B (E2/PB), U11.S
unnamed: U9.C (EGND/PW), U12.S
unnamed: U13.A (E1/PA), U14.S
unnamed: U13.B (E2/PB), U15.S
unnamed: U13.C (EGND/PW), U16.S
unnamed: U17.A (E1/PA), U18.S
unnamed: U17.B (E2/PB), U19.S
unnamed: U17.C (EGND/PW), U20.S
unnamed: U21.A (E1/PA), U22.S
unnamed: U21.B (E2/PB), U23.S
unnamed: U21.C (EGND/PW), U24.S
unnamed: U25.A (E1/PA), U26.S
unnamed: U25.B (E2/PB), U27.S
unnamed: U25.C (EGND/PW), U28.S
unnamed: U29.A (E1/PA), U30.S
unnamed: U29.B (E2/PB), U31.S
unnamed: U29.C (EGND/PW), U32.S
unnamed: U33.A (E1/PA), U34.S
unnamed: U33.B (E2/PB), U35.S
unnamed: U33.C (EGND/PW), U36.S
unnamed: U37.A (E1/PA), U38.S
unnamed: U37.B (E2/PB), U39.S
unnamed: U37.C (EGND/PW), U40.S
unnamed: U41.A (E1/PA), U44.S
unnamed: U41.B (E2/PB), U45.S
unnamed: U41.C (EGND/PW), U46.S
unnamed: U49.A (E1/PA), U50.S
unnamed: U49.B (E2/PB), U51.S
unnamed: U49.C (EGND/PW), U52.S

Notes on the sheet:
ENC S1
ENC S2

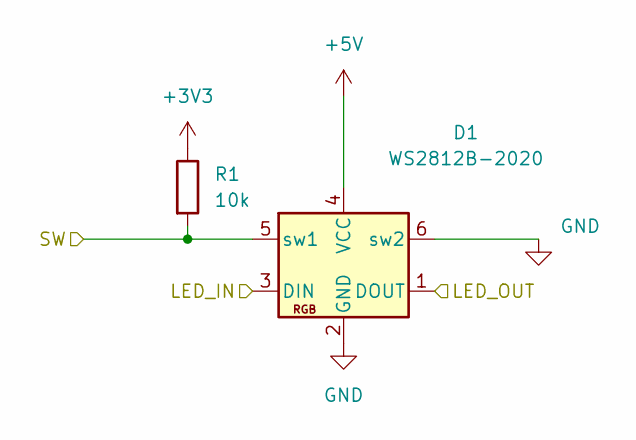
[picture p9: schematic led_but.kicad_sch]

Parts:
D1: WS2812B-2020; A3_CherryMxHybrid_WS2812Led2020
R1: 10k; R_1206_3216Metric_Pad1.30x1.75mm_HandSolder

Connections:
+3V3: R1.1; also elsewhere on the board
+5V: D1.4 (VCC); also elsewhere on the board
/LED/LedBut1/LED_OUT: D1.1 (DOUT); also elsewhere on the board
/LED/SW09: D1.5 (sw1), R1.2; also elsewhere on the board
GND: D1.2 (GND), D1.6 (sw2); also elsewhere on the board
led_dat: D1.3 (DIN); also elsewhere on the board

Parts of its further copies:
D2, D3, D4, D5, D6, D7, D8, D9, D10, D11, D12, D13, D14, D15, D16, D17, D18, D19, D20, D21, D22, D23, D24, D25, D26, D27, D28, D29, D30, D31, D32, D33, D34, D35, D36, D37, D38, D39, D40, D41, D42, D43, D44: WS2812B-2020; A3_CherryMxHybrid_WS2812Led2020
R2, R3, R4, R5, R6, R12, R13, R14, R15, R16, R17, R22, R23, R24, R25, R26, R27, R28, R33, R38, R39, R40, R45, R46, R52, R53, R54, R60, R61, R62, R68, R69, R70, R71, R77, R78, R79, R80, R81, R82, R83, R84, R85, R86, R87, R89, R100: 10k; R_1206_3216Metric_Pad1.30x1.75mm_HandSolder

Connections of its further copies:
+3V3: R2.1, R3.1, R4.1, R5.1, R6.1, R12.1, R13.1, R14.1, R15.1, R16.1, R17.2, R22.1, R23.1, R24.1, R25.1, R26.1, R27.1, R28.2, R33.2, R38.1, R39.1, R40.2, R45.1, R46.1, R52.1, R53.1, R54.1, R60.1, R61.1, R62.1, R68.1, R69.1, R70.1, R71.1, R77.1, R78.1, R79.1, R80.1, R81.1, R82.1, R83.1, R84.1, R85.1, R86.1, R87.1, R89.1, R100.1; also elsewhere on the board
+5V: D2.4 (VCC), D3.4 (VCC), D4.4 (VCC), D5.4 (VCC), D6.4 (VCC), D7.4 (VCC), D8.4 (VCC), D9.4 (VCC), D10.4 (VCC), D11.4 (VCC), D12.4 (VCC), D13.4 (VCC), D14.4 (VCC), D15.4 (VCC), D16.4 (VCC), D17.4 (VCC), D18.4 (VCC), D19.4 (VCC), D20.4 (VCC), D21.4 (VCC), D22.4 (VCC), D23.4 (VCC), D24.4 (VCC), D25.4 (VCC), D26.4 (VCC), D27.4 (VCC), D28.4 (VCC), D29.4 (VCC), D30.4 (VCC), D31.4 (VCC), D32.4 (VCC), D33.4 (VCC), D34.4 (VCC), D35.4 (VCC), D36.4 (VCC), D37.4 (VCC), D38.4 (VCC), D39.4 (VCC), D40.4 (VCC), D41.4 (VCC), D42.4 (VCC), D43.4 (VCC), D44.4 (VCC); also elsewhere on the board
/LED/LedBut1/LED_OUT: D2.3 (DIN); also elsewhere on the board
/LED/LedBut2/LED_OUT: D2.1 (DOUT), D3.3 (DIN)
/LED/LedBut3/LED_OUT: D3.1 (DOUT), D4.3 (DIN)
/LED/LedBut4/LED_OUT: D4.1 (DOUT), D5.3 (DIN)
/LED/LedBut5/LED_OUT: D5.1 (DOUT), D6.3 (DIN)
/LED/LedBut8/LED_IN: D7.3 (DIN), D8.1 (DOUT)
/LED/LedBut10/LED_IN: D6.1 (DOUT), D9.3 (DIN)
/LED/LedBut10/LED_OUT: D8.3 (DIN), D9.1 (DOUT)
/LED/LedBut13/LED_IN: D12.3 (DIN), D36.1 (DOUT)
/LED/LedBut13/LED_OUT: D12.1 (DOUT), D13.3 (DIN)
/LED/LedBut14/LED_OUT: D13.1 (DOUT), D14.3 (DIN)
/LED/LedBut15/LED_OUT: D14.1 (DOUT), D17.3 (DIN)
/LED/LedBut16/LED_IN: D15.3 (DIN), D16.1 (DOUT)
/LED/LedBut16/LED_OUT: D15.1 (DOUT), D37.3 (DIN)
/LED/LedBut17/LED_IN: D16.3 (DIN), D17.1 (DOUT)
/LED/LedBut21/LED_IN: D18.3 (DIN), D38.1 (DOUT)
/LED/LedBut21/LED_OUT: D18.1 (DOUT), D20.3 (DIN)
/LED/LedBut22/LED_IN: D10.3 (DIN), D11.1 (DOUT)
/LED/LedBut22/LED_OUT: D10.1 (DOUT), D40.3 (DIN)
/LED/LedBut23/LED_OUT: D20.1 (DOUT), D21.3 (DIN)
/LED/LedBut24/LED_OUT: D19.3 (DIN), D21.1 (DOUT)
/LED/LedBut25/LED_IN: D11.3 (DIN), D19.1 (DOUT)
/LED/LedBut28/LED_IN: D22.3 (DIN), D23.1 (DOUT)
/LED/LedBut28/LED_OUT: D22.1 (DOUT), D43.3 (DIN)
/LED/LedBut30/LED_IN: D25.3 (DIN), D42.1 (DOUT)
/LED/LedBut30/LED_OUT: D25.1 (DOUT), D26.3 (DIN)
/LED/LedBut31/LED_OUT: D26.1 (DOUT), D27.3 (DIN)
/LED/LedBut32/LED_OUT: D24.3 (DIN), D27.1 (DOUT)
/LED/LedBut33/LED_IN: D23.3 (DIN), D24.1 (DOUT)
/LED/LedBut36/LED_IN: D28.3 (DIN), D29.1 (DOUT)
/LED/LedBut36/LED_OUT: D28.1 (DOUT), D31.3 (DIN)
/LED/LedBut37/LED_IN: D29.3 (DIN), D30.1 (DOUT)
/LED/LedBut39/LED_IN: D32.3 (DIN), D44.1 (DOUT)
/LED/LedBut39/LED_OUT: D32.1 (DOUT), D33.3 (DIN)
/LED/LedBut40/LED_OUT: D33.1 (DOUT), D34.3 (DIN)
/LED/LedBut41/LED_OUT: D30.3 (DIN), D34.1 (DOUT)
/LED/LedBut45/LED_OUT: D31.1 (DOUT), D41.3 (DIN)
/LED/LedBut47/LED_IN: D39.3 (DIN), D41.1 (DOUT)
/LED/LedBut47/LED_OUT: D39.1 (DOUT)
/LED/LedBut55/LED_IN: D7.1 (DOUT), D35.3 (DIN)
/LED/LedBut55/LED_OUT: D35.1 (DOUT), D36.3 (DIN)
/LED/LedBut57/LED_OUT: D37.1 (DOUT), D38.3 (DIN)
/LED/LedBut59/LED_OUT: D40.1 (DOUT), D42.3 (DIN)
/LED/LedBut61/LED_OUT: D43.1 (DOUT), D44.3 (DIN)
/LED/SW00: D39.5 (sw1), R84.2; also elsewhere on the board
/LED/SW10: D41.5 (sw1), R86.2; also elsewhere on the board
/LED/SW19: D2.5 (sw1), R2.2; also elsewhere on the board
/LED/SW20: D31.5 (sw1), R71.2; also elsewhere on the board
/LED/SW21: D44.5 (sw1), R100.2; also elsewhere on the board
/LED/SW22: D43.5 (sw1), R89.2; also elsewhere on the board
/LED/SW23: D42.5 (sw1), R87.2; also elsewhere on the board
/LED/SW24: D40.5 (sw1), R85.2; also elsewhere on the board
/LED/SW25: D38.5 (sw1), R83.2; also elsewhere on the board
/LED/SW26: D37.5 (sw1), R82.2; also elsewhere on the board
/LED/SW27: D36.5 (sw1), R81.2; also elsewhere on the board
/LED/SW28: D35.5 (sw1), R80.2; also elsewhere on the board
/LED/SW29: D3.5 (sw1), R3.2; also elsewhere on the board
/LED/SW30: D28.5 (sw1), R68.2; also elsewhere on the board
/LED/SW31: D32.5 (sw1), R77.2; also elsewhere on the board
/LED/SW32: D22.5 (sw1), R52.2; also elsewhere on the board
/LED/SW33: D25.5 (sw1), R60.2; also elsewhere on the board
/LED/SW34: D10.5 (sw1), R15.2; also elsewhere on the board
/LED/SW35: D18.5 (sw1), R38.2; also elsewhere on the board
/LED/SW36: D15.5 (sw1), R25.2; also elsewhere on the board
/LED/SW37: D12.5 (sw1), R22.2; also elsewhere on the board
/LED/SW38: D7.5 (sw1), R12.2; also elsewhere on the board
/LED/SW39: D4.5 (sw1), R4.2; also elsewhere on the board
/LED/SW40: D29.5 (sw1), R69.2; also elsewhere on the board
/LED/SW41: D33.5 (sw1), R78.2; also elsewhere on the board
/LED/SW42: D23.5 (sw1), R53.2; also elsewhere on the board
/LED/SW43: D26.5 (sw1), R61.2; also elsewhere on the board
/LED/SW44: D11.5 (sw1), R16.2; also elsewhere on the board
/LED/SW45: D20.5 (sw1), R45.2; also elsewhere on the board
/LED/SW46: D16.5 (sw1), R26.2; also elsewhere on the board
/LED/SW47: D13.5 (sw1), R23.2; also elsewhere on the board
/LED/SW48: D8.5 (sw1), R13.2; also elsewhere on the board
/LED/SW49: D5.5 (sw1), R5.2; also elsewhere on the board
/LED/SW50: D30.5 (sw1), R70.2; also elsewhere on the board
/LED/SW51: D34.5 (sw1), R79.2; also elsewhere on the board
/LED/SW52: D24.5 (sw1), R54.2; also elsewhere on the board
/LED/SW53: D27.5 (sw1), R62.2; also elsewhere on the board
/LED/SW54: D19.5 (sw1), R39.2; also elsewhere on the board
/LED/SW55: D21.5 (sw1), R46.2; also elsewhere on the board
/LED/SW56: D17.5 (sw1), R27.2; also elsewhere on the board
/LED/SW57: D14.5 (sw1), R24.2; also elsewhere on the board
/LED/SW58: D9.5 (sw1), R14.2; also elsewhere on the board
/LED/SW59: D6.5 (sw1), R6.2; also elsewhere on the board
/mux/ES01: R40.1; also elsewhere on the board
/mux/ES03: R28.1; also elsewhere on the board
/mux/ES12: R17.1; also elsewhere on the board
/mux/ES23: R33.1; also elsewhere on the board
GND: D2.2 (GND), D2.6 (sw2), D3.2 (GND), D3.6 (sw2), D4.2 (GND), D4.6 (sw2), D5.2 (GND), D5.6 (sw2), D6.2 (GND), D6.6 (sw2), D7.2 (GND), D7.6 (sw2), D8.2 (GND), D8.6 (sw2), D9.2 (GND), D9.6 (sw2), D10.2 (GND), D10.6 (sw2), D11.2 (GND), D11.6 (sw2), D12.2 (GND), D12.6 (sw2), D13.2 (GND), D13.6 (sw2), D14.2 (GND), D14.6 (sw2), D15.2 (GND), D15.6 (sw2), D16.2 (GND), D16.6 (sw2), D17.2 (GND), D17.6 (sw2), D18.2 (GND), D18.6 (sw2), D19.2 (GND), D19.6 (sw2), D20.2 (GND), D20.6 (sw2), D21.2 (GND), D21.6 (sw2), D22.2 (GND), D22.6 (sw2), D23.2 (GND), D23.6 (sw2), D24.2 (GND), D24.6 (sw2), D25.2 (GND), D25.6 (sw2), D26.2 (GND), D26.6 (sw2), D27.2 (GND), D27.6 (sw2), D28.2 (GND), D28.6 (sw2), D29.2 (GND), D29.6 (sw2), D30.2 (GND), D30.6 (sw2), D31.2 (GND), D31.6 (sw2), D32.2 (GND), D32.6 (sw2), D33.2 (GND), D33.6 (sw2), D34.2 (GND), D34.6 (sw2), D35.2 (GND), D35.6 (sw2), D36.2 (GND), D36.6 (sw2), D37.2 (GND), D37.6 (sw2), D38.2 (GND), D38.6 (sw2), D39.2 (GND), D39.6 (sw2), D40.2 (GND), D40.6 (sw2), D41.2 (GND), D41.6 (sw2), D42.2 (GND), D42.6 (sw2), D43.2 (GND), D43.6 (sw2), D44.2 (GND), D44.6 (sw2); also elsewhere on the board

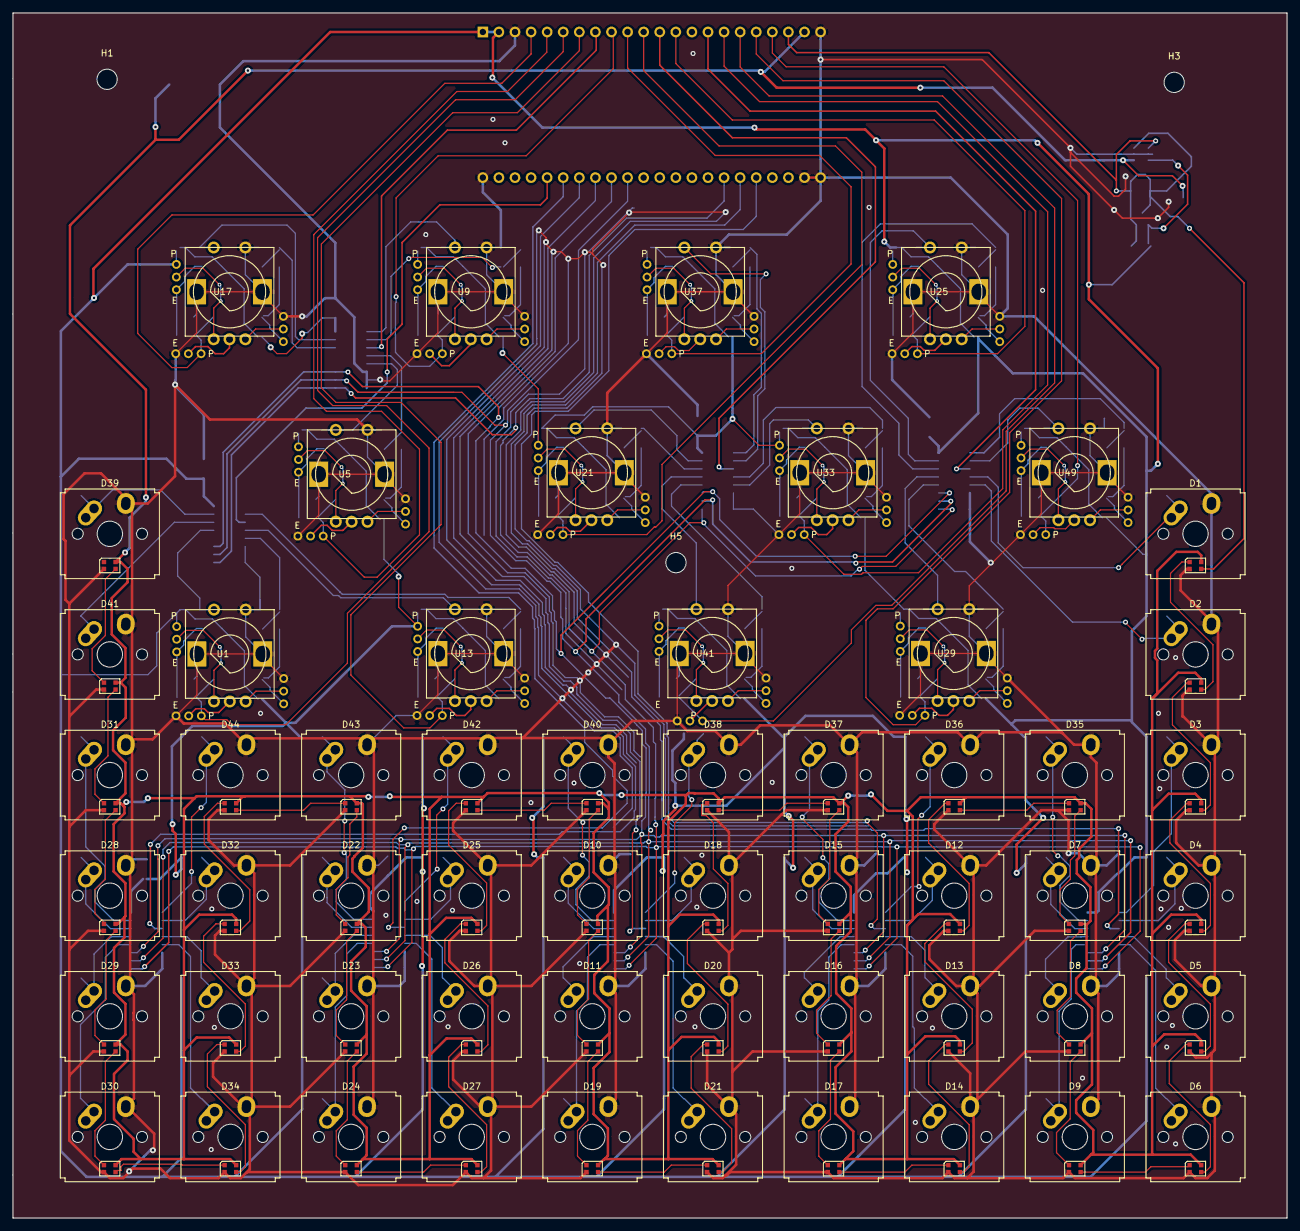
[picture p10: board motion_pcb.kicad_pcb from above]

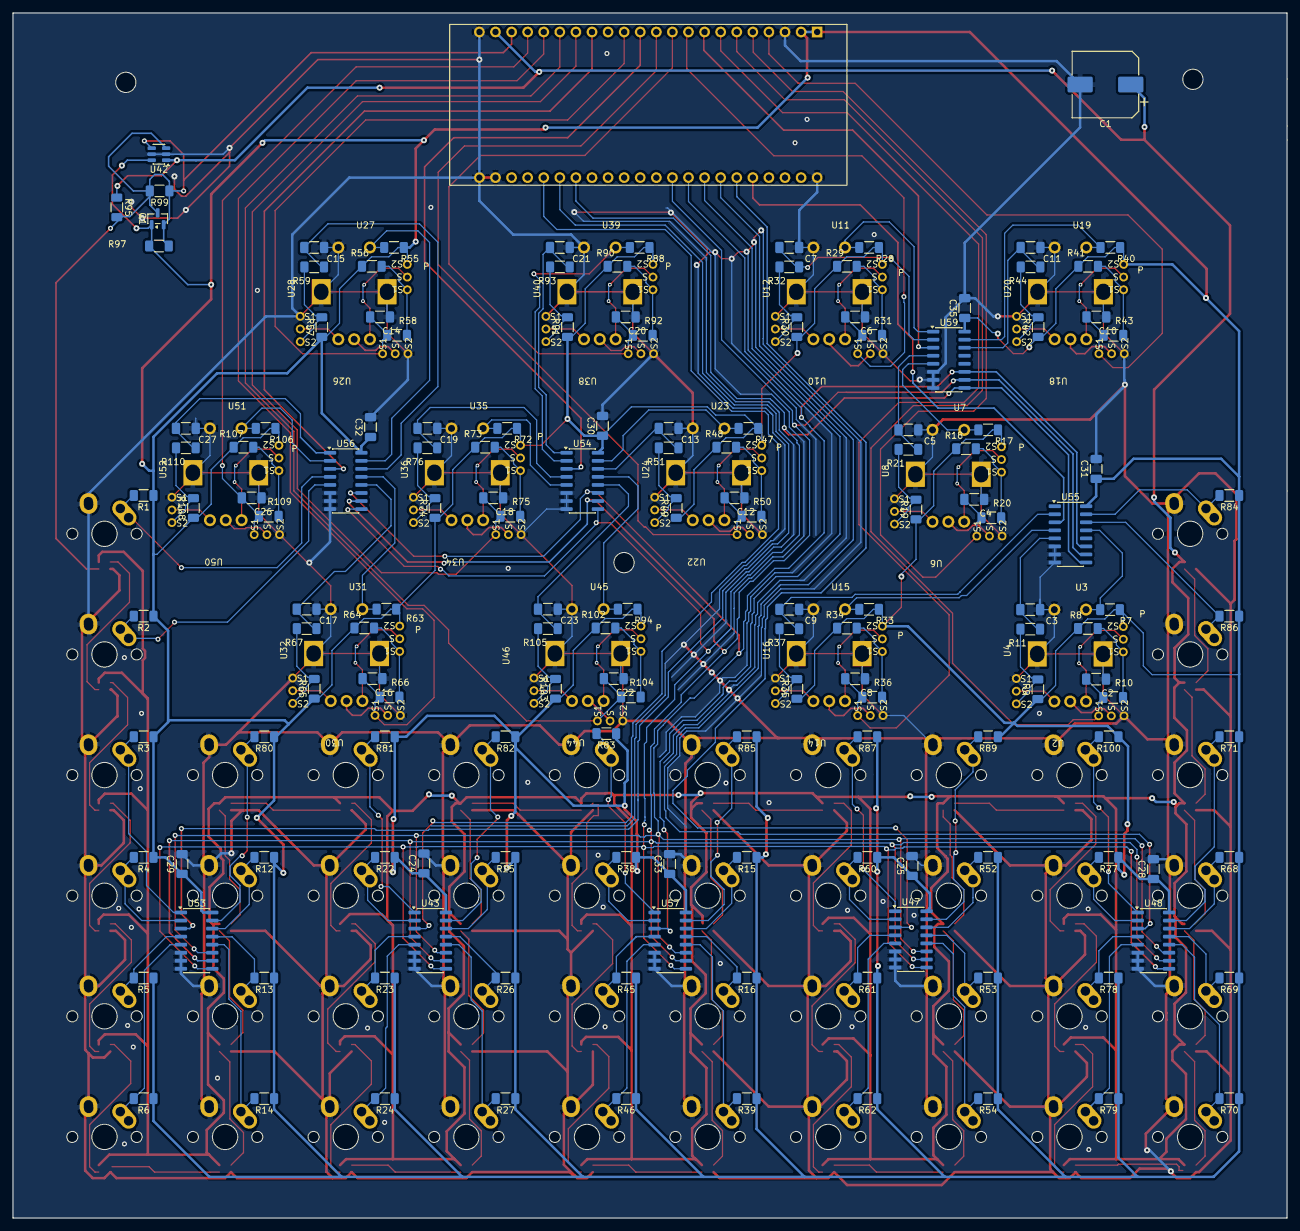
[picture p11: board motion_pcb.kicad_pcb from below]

Board: 2 copper layers, 201.2 x 190.3 mm, 251 parts (189 on the bottom side), 199 nets.

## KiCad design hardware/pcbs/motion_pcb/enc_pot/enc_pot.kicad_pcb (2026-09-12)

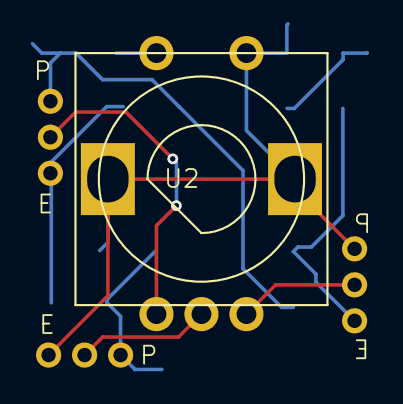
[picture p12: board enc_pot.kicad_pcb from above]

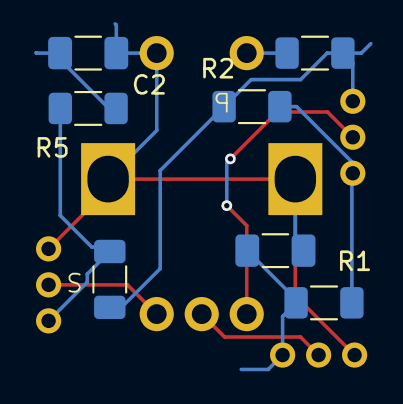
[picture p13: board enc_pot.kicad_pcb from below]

Board: 2 copper layers, 11 parts (10 on the bottom side), 10 nets.

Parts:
C1, C2: 100nF; C_1206_3216Metric_Pad1.33x1.80mm_HandSolder
R1, R5: 1k; R_1206_3216Metric_Pad1.30x1.75mm_HandSolder
R2, R4: 10K; R_1206_3216Metric_Pad1.30x1.75mm_HandSolder
R3: 10k; R_1206_3216Metric_Pad1.30x1.75mm_HandSolder
U1, U3, U4: a3_jumper_fix
U2: A3_ENC_POT_mix

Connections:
+3V3: R2.1, R3.2, R4.1, U1.S2
/EB/-: C2.1, R5.1
/ESW: R3.1, U2.S2
GND: C1.2, C2.2, U2.S1, U2.SH1 (shield), U2.SH2 (shield), U3.S2, U4.S1
unnamed: R1.2, R2.2, U1.S1
unnamed: R4.2, R5.2, U4.S2
unnamed: U1.S, U2.A (E1/PA)
unnamed: U2.B (E2/PB), U4.S
unnamed: U2.C (EGND/PW), U3.S
POT_H: C1.1, R1.1, U3.S1

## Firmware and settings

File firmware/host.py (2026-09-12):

#!/usr/bin/env python3
"""
a3-motion host – polls the firmware and prints human-readable input events.

Usage:
    python3 host.py [PORT] [-v|--verbose] [--no-hold]
                    [--poti-divider N] [--poti-threshold N] [--poti-leds] [--enc-leds]  (default: auto)

    -v / --verbose  Print all encoder and pot values every cycle,
                    not just changes. Useful to verify hardware connections.
    --no-hold       Suppress continuously pressed buttons (HOLD).
    --poti-divider  Read pots every Nth cycle (default: 1 = every cycle).
    --poti-threshold  Minimum ADC delta to report in non-verbose mode (default: 2).
    --poti-leds     Drive LEDs 0-43 as a fill bar from POT1 for latency testing.
    --enc-leds      Drive LEDs 0-43 as a fill bar from ENCODER1 for latency testing.

Protocol (firmware/include/protocol.h):
    0x01  PING         → [0x01]                           1 B
    0x02  GET_POTS     → [0x02] + 4 × u16 LE              9 B
    0x03  GET_ENCODERS → [0x03] + 8 × (i16 LE, u8)       25 B
    0x04  GET_BUTTONS  → [0x04] + 11 packed bytes         12 B
"""

import sys
import time
import struct
import serial
from serial.tools import list_ports

# ── button labels in MATRIX_BUTTONS[] order ──────────────────────────────────
BUTTON_LABELS = [
    "40","30","20","50", "21","51","31","41",
    "42","32","22","52", "23","53","33","43",
    "44","34","24","54", "25","55","35","45",
    "46","36","26","56", "27","57","37","47",
    "48","38","28","58", "29","59","39","49",
    "00","10","09","19",
]

# ── 2-bit button-state meanings ───────────────────────────────────────────────
# bit0 = current level (0=pressed/LOW, 1=released/HIGH)
# bit1 = sawRise && sawFall (full cycle happened)
STATE_LABEL = {0: "HOLD", 1: "-", 2: "BOUNCE", 3: "CLICK"}

DEFAULT_POT_DIVIDER = 1  # poll pots every cycle for direct feel
DEFAULT_POT_THRESHOLD = 4

# Pre-built command batches: send all commands for a cycle in one write,
# receive all responses in one blocking read.
#   BTN(12) + ENC(25)          = 37 bytes  (normal cycle)
#   BTN(12) + ENC(25) + POT(9) = 46 bytes  (pot cycle)
_CMD_BTN_ENC     = bytes([0x04, 0x03])
_CMD_BTN_ENC_POT = bytes([0x04, 0x03, 0x02])

_CMD_SET_LED = 0x05
_CMD_SET_ALL_LEDS = 0x06
LED_ON_RGB = (0, 0, 255)
LED_OFF_RGB = (0, 0, 0)

# LED index -> button label mapping, matching firmware LED_MAP[]
LED_BUTTON_LABELS = [
    "09", "19", "29", "39", "49", "59",
    "58", "48", "38", "28",
    "27", "37", "47", "57",
    "56", "46", "36", "26",
    "25", "35", "45", "55",
    "54", "44", "34", "24",
    "23", "33", "43", "53",
    "52", "42", "32", "22",
    "21", "31", "41", "51",
    "50", "40", "30", "20", "10", "00",
]

_BUTTON_INDEX_BY_LABEL = {label: i for i, label in enumerate(BUTTON_LABELS)}
_LED_BUTTON_INDEX = [_BUTTON_INDEX_BY_LABEL[label] for label in LED_BUTTON_LABELS]

# Timeout long enough for 3 × firmware loop delay (3 × 20 ms) + margin.
# A single port.read(n) call blocks until all n bytes arrive or this elapses.
SERIAL_TIMEOUT = 0.25
TEST_LED_START = 0
TEST_LED_COUNT = 44
ENC_LED_MIN_POS = 0
ENC_LED_MAX_POS = TEST_LED_COUNT


def _auto_detect_port() -> str:
    """Pick a likely serial device, preferring Linux ACM then USB adapters."""
    devices = [p.device for p in list_ports.comports()]

    # Prefer native USB CDC devices first (most ESP32-S3 boards show as ACM).
    for dev in devices:
        if "/dev/ttyACM" in dev:
            return dev

    # Then prefer USB-UART adapters.
    for dev in devices:
        if "/dev/ttyUSB" in dev:
            return dev

    # Fallback: return first discovered serial port, if any.
    if devices:
        return devices[0]

    raise RuntimeError("No serial port found. Connect device or pass PORT explicitly.")


def read_exact(port: serial.Serial, n: int) -> bytes:
    """Block until exactly n bytes are received (relies on SERIAL_TIMEOUT)."""
    data = port.read(n)
    if len(data) != n:
        raise TimeoutError(f"expected {n} B, got {len(data)}")
    return data


def _validate_frame(raw: bytes, with_pots: bool) -> None:
    """Validate response markers and return dynamic frame offsets.

    Some USB-CDC stacks may deliver command responses in ENC+BTN order.
    Accept both layouts and parse by detected markers.
    """
    if len(raw) < (46 if with_pots else 37):
        raise ValueError(f"short frame: {len(raw)} bytes")

    # Layout A: BTN(12) + ENC(25) [+ POT(9)]
    if raw[0] == 0x04 and raw[12] == 0x03:
        if with_pots and raw[37] != 0x02:
            raise ValueError(f"bad pot frame marker: {raw[37]}")
        return 0, 12, (37 if with_pots else None)

    # Layout B: ENC(25) + BTN(12) [+ POT(9)]
    if raw[0] == 0x03 and raw[25] == 0x04:
        if with_pots and raw[37] != 0x02:
            raise ValueError(f"bad pot frame marker: {raw[37]}")
        return 25, 0, (37 if with_pots else None)

    raise ValueError(f"bad markers: b0={raw[0]} b12={raw[12]} b25={raw[25]}")


def _process_buttons(raw: bytes, offset: int, prev_down: list, show_hold: bool) -> None:
    """Parse 12-byte button frame and print button edge events."""
    if raw[offset] != 0x04:
        return
    packed = raw
    base = offset + 1
    events = []
    for i in range(44):
        state = (packed[base + (i >> 2)] >> ((i & 3) << 1)) & 0x03
        # Current debounced level: 0/2 => pressed, 1/3 => released.
        is_down = state in (0, 2)
        if is_down and not prev_down[i]:
            events.append(f"BTN_{BUTTON_LABELS[i]}=PRESS")
        elif (not is_down) and prev_down[i]:
            events.append(f"BTN_{BUTTON_LABELS[i]}=RELEASE")

        if show_hold and state == 0:
            events.append(f"BTN_{BUTTON_LABELS[i]}=HOLD")

        # Keep explicit click info when firmware reports a full round-trip.
        if state == 3:
            events.append(f"BTN_{BUTTON_LABELS[i]}=CLICK")

        prev_down[i] = is_down
    if events:
        print("BUTTONS  ", "  ".join(events))


def _decode_button_states(raw: bytes, offset: int) -> list:
    """Return 44 unpacked button states from a 12-byte button frame."""
    if raw[offset] != 0x04:
        return [1] * 44
    packed = raw
    base = offset + 1
    return [
        (packed[base + (i >> 2)] >> ((i & 3) << 1)) & 0x03
        for i in range(44)
    ]


def _set_led(port: serial.Serial, led_id: int, r: int, g: int, b: int) -> None:
    """Send one SET_LED command (no response expected)."""
    port.write(bytes([_CMD_SET_LED, led_id, r, g, b]))


def _apply_pot_led_test(port: serial.Serial, pot_vals: list, prev_level: int | None) -> int:
    """Use POT1 as a 44-step fill bar on LEDs 0..43."""
    level = (pot_vals[0] * TEST_LED_COUNT + 2047) // 4095  # 0..44 with rounded mapping
    if prev_level == level:
        return level

    if prev_level is None:
        # First update initializes the complete bar state.
        for step in range(TEST_LED_COUNT):
            led_id = TEST_LED_START + step
            if step < level:
                _set_led(port, led_id, 0, 0, 255)
            else:
                _set_led(port, led_id, 0, 0, 0)
        return level

    # Only touch LEDs that actually changed between previous and new level.
    if level > prev_level:
        for step in range(prev_level, level):
            _set_led(port, TEST_LED_START + step, 0, 0, 255)
    else:
        for step in range(level, prev_level):
            _set_led(port, TEST_LED_START + step, 0, 0, 0)
    return level


def _apply_encoder_led_test(
    port: serial.Serial,
    enc_deltas: list,
    enc_position: int,
    prev_level: int | None,
):
    """Use ENCODER1 as a 44-step fill bar on LEDs 0..43."""
    enc_position = max(ENC_LED_MIN_POS, min(ENC_LED_MAX_POS, enc_position + enc_deltas[0]))
    level = enc_position

    if prev_level == level:
        return enc_position, level

    if prev_level is None:
        for step in range(TEST_LED_COUNT):
            led_id = TEST_LED_START + step
            if step < level:
                _set_led(port, led_id, 0, 255, 40)
            else:
                _set_led(port, led_id, 0, 0, 0)
        return enc_position, level

    if level > prev_level:
        for step in range(prev_level, level):
            _set_led(port, TEST_LED_START + step, 0, 255, 40)
    else:
        for step in range(level, prev_level):
            _set_led(port, TEST_LED_START + step, 0, 0, 0)
    return enc_position, level


def _apply_button_led_toggle(port: serial.Serial, states: list, led_on: list, prev_pressed: list) -> None:
    """Replicate firmware behavior: toggle LED on new button press edge."""
    for led_id, button_idx in enumerate(_LED_BUTTON_INDEX):
        pressed = (states[button_idx] == 0)
        if pressed and not prev_pressed[button_idx]:
            led_on[led_id] = not led_on[led_id]
            r, g, b = LED_ON_RGB if led_on[led_id] else LED_OFF_RGB
            _set_led(port, led_id, r, g, b)
        prev_pressed[button_idx] = pressed


def _process_encoders(
    raw: bytes,
    offset: int,
    verbose: bool,
    prev_sw_down: list,
    show_hold: bool,
) -> None:
    """Parse 25-byte encoder frame starting at raw[offset]."""
    if raw[offset] != 0x03:
        return [0] * 8
    events = []
    deltas = [0] * 8
    base = offset + 1
    for i in range(8):
        o = base + i * 3
        delta = struct.unpack_from("<h", raw, o)[0]
        deltas[i] = delta
        sw    = raw[o + 2]

        if verbose and delta != 0:
            direction = "CW" if delta > 0 else ("CCW" if delta < 0 else "--")
            events.append(f"ENC{i+1}={direction}({delta:+d})")

        if not verbose and delta != 0:
            direction = "CW" if delta > 0 else "CCW"
            events.append(f"ENC{i+1}={direction}({delta:+d})")

        # Current debounced level: 0/2 => pressed, 1/3 => released.
        is_down = sw in (0, 2)
        if is_down and not prev_sw_down[i]:
            events.append(f"ENC{i+1}_SW=PRESS")
        elif (not is_down) and prev_sw_down[i]:
            events.append(f"ENC{i+1}_SW=RELEASE")

        if show_hold and sw == 0:
            events.append(f"ENC{i+1}_SW=HOLD")
        if sw == 3:
            events.append(f"ENC{i+1}_SW=CLICK")

        prev_sw_down[i] = is_down
    if events:
        print("ENCODERS ", "  ".join(events))
    return deltas


def _process_pots(
    raw: bytes,
    offset: int,
    prev: list,
    verbose: bool,
    threshold: int,
):
    """Parse 9-byte pot frame and report raw values with deadband."""
    if raw[offset] != 0x02:
        return prev
    vals = list(struct.unpack_from("<4H", raw, offset + 1))

    if verbose:
        print("POTS     ", "  ".join(f"POT{i+1}={vals[i]}" for i in range(4)))
    else:
        changed = [f"POT{i+1}={vals[i]}" for i in range(4)
                   if abs(vals[i] - prev[i]) >= threshold]
        if changed:
            print("POTS     ", "  ".join(changed))
    return vals


def main():
    args = sys.argv[1:]
    verbose = "-v" in args or "--verbose" in args
    show_hold = "--no-hold" not in args
    poti_leds_mode = "--poti-leds" in args
    enc_leds_mode = "--enc-leds" in args
    pot_divider = DEFAULT_POT_DIVIDER
    pot_threshold = DEFAULT_POT_THRESHOLD

    i = 0
    cleaned_args = []
    while i < len(args):
        a = args[i]
        if a in ("-v", "--verbose", "--no-hold", "--poti-leds", "--enc-leds"):
            i += 1
            continue
        if a == "--poti-divider" and i + 1 < len(args):
            pot_divider = max(1, int(args[i + 1]))
            i += 2
            continue
        if a == "--poti-threshold" and i + 1 < len(args):
            pot_threshold = max(0, int(args[i + 1]))
            i += 2
            continue
        cleaned_args.append(a)
        i += 1

    args = cleaned_args
    port_name = args[0] if args else _auto_detect_port()
    print(f"Connecting to {port_name} …" + (" [verbose]" if verbose else ""))

    with serial.Serial(port_name, 115200, timeout=SERIAL_TIMEOUT) as port:
        time.sleep(0.1)
        port.reset_input_buffer()
        print("Ready. Press Ctrl-C to quit.\n")

        pot_vals = [0, 0, 0, 0]
        led_on = [False] * 44
        prev_pressed = [False] * 44
        prev_down_print = [False] * 44
        prev_enc_sw_down = [False] * 8
        prev_pot_led_level = None
        prev_enc_led_level = None
        enc_led_position = 0
        cycle = 0
        while True:
            try:
                if cycle % pot_divider == 0:
                    port.write(_CMD_BTN_ENC_POT)
                    raw = read_exact(port, 46)
                    btn_off, enc_off, pot_off = _validate_frame(raw, with_pots=True)
                    states = _decode_button_states(raw, btn_off)
                    _process_buttons(raw, btn_off, prev_down_print, show_hold)
                    enc_deltas = _process_encoders(raw, enc_off, verbose, prev_enc_sw_down, show_hold)
                    pot_vals = _process_pots(raw, pot_off, pot_vals, verbose, pot_threshold)
                    if poti_leds_mode:
                        prev_pot_led_level = _apply_pot_led_test(port, pot_vals, prev_pot_led_level)
                    if enc_leds_mode:
                        enc_led_position, prev_enc_led_level = _apply_encoder_led_test(
                            port, enc_deltas, enc_led_position, prev_enc_led_level
                        )
                else:
                    port.write(_CMD_BTN_ENC)
                    raw = read_exact(port, 37)
                    btn_off, enc_off, _ = _validate_frame(raw, with_pots=False)
                    states = _decode_button_states(raw, btn_off)
                    _process_buttons(raw, btn_off, prev_down_print, show_hold)
                    enc_deltas = _process_encoders(raw, enc_off, verbose, prev_enc_sw_down, show_hold)
                    if enc_leds_mode:
                        enc_led_position, prev_enc_led_level = _apply_encoder_led_test(
                            port, enc_deltas, enc_led_position, prev_enc_led_level
                        )

                if not poti_leds_mode and not enc_leds_mode:
                    _apply_button_led_toggle(port, states, led_on, prev_pressed)
                cycle += 1
            except TimeoutError as e:
                print(f"[timeout] {e}")
                port.reset_input_buffer()
                cycle = 0
            except ValueError as e:
                print(f"[desync] {e}")
                port.reset_input_buffer()
                cycle = 0


if __name__ == "__main__":
    try:
        main()
    except KeyboardInterrupt:
        print("\nBye.")

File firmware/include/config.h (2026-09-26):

#ifndef A3_MOTION_FIRMWARE_CONFIG_H
#define A3_MOTION_FIRMWARE_CONFIG_H

#include <Arduino.h>

constexpr uint8_t LED_PIN = 14;
constexpr uint8_t NUMPIXELS = 44;

// How much the 44 key LEDs may draw together, as led_budget.h estimates it
// -- the datasheet's figures, not what a meter would read. They hang on the
// USB 5 V of a USB 2.0 port on the NUC.
//
// Set from what the app really shows (a3-motion-ui#21): its own copy of the
// estimate logged every new peak while the maintainer played a full session
// on 2026-09-26. The highest was 1144, the resting picture -- the idle colour
// lights every key, and playing changes colours rather than adding light.
// That picture has run on this port for months, so it is known to be safe;
// the budget sits about 14 % above it. Normal use is never dimmed, and full
// white on every key (about 2700 by this estimate) is halved.
//
// Not measured with a meter: if one ever is, the per-colour figure in
// led_budget.h is what to calibrate, and this number with it.
constexpr uint32_t LED_BUDGET_MA = 1300;

constexpr uint8_t BUTTON_MUX_COUNT = 5;
constexpr uint8_t MUX_CHANNEL_COUNT = 8;
constexpr uint8_t EXTRA_BUTTON_COUNT = 4;
constexpr uint8_t MATRIX_BUTTON_COUNT = (BUTTON_MUX_COUNT * MUX_CHANNEL_COUNT) + EXTRA_BUTTON_COUNT;
constexpr uint8_t ENCODER_COUNT = 8;
constexpr uint8_t POT_MUX_COUNT = 4;
constexpr uint8_t SELECT_PIN_COUNT = 3;
constexpr uint8_t LED_MATRIX_ROWS = 6;
constexpr uint8_t LED_MATRIX_COLS = 10;
constexpr uint8_t LED_MATRIX_A3_START_ROW = 1;
constexpr uint8_t LED_MATRIX_A3_START_COL = 1;
constexpr uint8_t LED_MATRIX_A3_ROW_COUNT = 5;
constexpr uint8_t LED_MATRIX_A3_COL_COUNT = 9;

constexpr uint8_t BUTTON_RELEASE_DELAY_MS = 5;
constexpr uint8_t MUX_SETTLE_DELAY_US = 12;
constexpr uint32_t INPUT_SCAN_INTERVAL_US = 450;
constexpr uint32_t CMD_PROCESS_BUDGET_US = 650;
constexpr uint32_t LED_SHOW_MIN_INTERVAL_US = 0;
constexpr uint8_t PROTOCOL_PAYLOAD_TIMEOUT_MS = 3;
// Number of quadrature transitions per mechanical encoder detent.
// Most common mechanical encoders are 4; set to 2 if movement feels under-reported.
constexpr uint8_t ENCODER_COUNTS_PER_DETENT = 4;
constexpr uint8_t POT_OVERSAMPLE_COUNT = 8;
constexpr uint8_t POT_EMA_SHIFT = 2;      // stronger smoothing to calm ADC noise
constexpr uint8_t POT_DEADBAND = 5;       // suppress small ADC jitter
constexpr uint16_t POT_CLIP_MIN = 6;
constexpr uint16_t POT_CLIP_MAX = 4088;
constexpr uint16_t POT_CENTER_BAND_RAW = 900;
constexpr uint8_t POT_DEADBAND_CENTER_BONUS = 6;

constexpr uint8_t MUX_S0 = 39;
constexpr uint8_t MUX_S1 = 38;
constexpr uint8_t MUX_S2 = 48;

constexpr uint8_t MUX_0_GPIO = 41;//MAA01 Button20 bis 51
constexpr uint8_t MUX_1_GPIO = 42;//MAA23 Button22 bis 53
constexpr uint8_t MUX_2_GPIO = 40;//MAA45 Button24 bis 55
constexpr uint8_t MUX_3_GPIO = 21;//MAA67 Button26 bis 57
constexpr uint8_t MUX_4_GPIO = 47;//MAA89 Button28 bis 59
constexpr uint8_t MUX_5_GPIO = 2;//MA  Button00,01 ENC1 und ENC2
constexpr uint8_t MUX_6_GPIO = 15;//MB ENC5 
constexpr uint8_t MUX_7_GPIO = 8;//MC ENC3,ENC6,ENC7 
constexpr uint8_t MUX_8_GPIO = 9;//MD Button09,19 und ENC4,ENC8

constexpr uint8_t ENCODER_1A_PIN = 6;
constexpr uint8_t ENCODER_2A_PIN = 7;
constexpr uint8_t ENCODER_3A_PIN = 11;
constexpr uint8_t ENCODER_4A_PIN = 12;
constexpr uint8_t ENCODER_5A_PIN = 5;
constexpr uint8_t ENCODER_6A_PIN = 18;
constexpr uint8_t ENCODER_7A_PIN = 10;
constexpr uint8_t ENCODER_8A_PIN = 13;

constexpr uint8_t POT_1_PIN = 4;
constexpr uint8_t POT_2_PIN = 16;
constexpr uint8_t POT_3_PIN = 17;
constexpr uint8_t POT_4_PIN = 3;

constexpr uint8_t SELECT_PINS[SELECT_PIN_COUNT] = {
  MUX_S0,
  MUX_S1,
  MUX_S2
};

constexpr uint8_t MUX_PINS[9] = {
  MUX_0_GPIO,
  MUX_1_GPIO,
  MUX_2_GPIO,
  MUX_3_GPIO,
  MUX_4_GPIO,
  MUX_5_GPIO,
  MUX_6_GPIO,
  MUX_7_GPIO,
  MUX_8_GPIO
};

constexpr uint8_t ENCODER_A_PINS[ENCODER_COUNT] = {
  ENCODER_1A_PIN, ENCODER_2A_PIN, ENCODER_3A_PIN, ENCODER_4A_PIN,
  ENCODER_5A_PIN, ENCODER_6A_PIN, ENCODER_7A_PIN, ENCODER_8A_PIN
};

constexpr uint8_t POT_PINS[POT_MUX_COUNT] = {
  POT_1_PIN, POT_2_PIN, POT_3_PIN, POT_4_PIN
};

// Physical daisy-chain order on the board.
// First addressable LED is 09, last is 00.
constexpr uint8_t LED_PHYSICAL_ORDER[NUMPIXELS] = {
  9, 19, 29, 39, 49, 59,
  58, 48, 38, 28,
  27, 37, 47, 57,
  56, 46, 36, 26,
  25, 35, 45, 55,
  54, 44, 34, 24,
  23, 33, 43, 53,
  52, 42, 32, 22,
  21, 31, 41, 51,
  50, 40, 30, 20, 10, 0
};

constexpr int8_t LED_MATRIX[LED_MATRIX_ROWS][LED_MATRIX_COLS] = {
  { 43, -1, -1, -1, -1, -1, -1, -1, -1, 0 },
  { 42, -1, -1, -1, -1, -1, -1, -1, -1, 1 },
  { 41, 34, 33, 26, 25, 18, 17, 10, 9, 2 },
  { 40, 35, 32, 27, 24, 19, 16, 11, 8, 3 },
  { 39, 36, 31, 28, 23, 20, 15, 12, 7, 4 },
  { 38, 37, 30, 29, 22, 21, 14, 13, 6, 5 }
};

#endif

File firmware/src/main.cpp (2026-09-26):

#include <Adafruit_NeoPixel.h>
#include "led_output.h"

#include "a3_special.h"
#include "buttons.h"
#include "config.h"
#include "encoder.h"
#include "mux_io.h"
#include "multiplexer_map.h"
#include "potis.h"
#include "protocol.h"
#include "usart.h"

Adafruit_NeoPixel strip(NUMPIXELS, LED_PIN, NEO_GRB + NEO_KHZ800);

void setup() {
    // Configure MUX select lines as outputs
    for (uint8_t i = 0; i < SELECT_PIN_COUNT; i++) {
        pinMode(SELECT_PINS[i], OUTPUT);
        digitalWrite(SELECT_PINS[i], LOW);
    }

    // Button MUX output pins (MUX 0-4)
    for (uint8_t i = 0; i < BUTTON_MUX_COUNT; i++) {
        pinMode(MUX_PINS[i], INPUT_PULLUP);
    }

    // Encoder A direct pins
    for (uint8_t i = 0; i < ENCODER_COUNT; i++) {
        pinMode(ENCODER_A_PINS[i], INPUT_PULLUP);
    }

    // Encoder/extra-button MUX output pins (MUX 5-8)
    for (uint8_t i = BUTTON_MUX_COUNT; i < 9; i++) {
        pinMode(MUX_PINS[i], INPUT_PULLUP);
    }

    // Poti ADC pins
    for (uint8_t i = 0; i < POT_MUX_COUNT; i++) {
        pinMode(POT_PINS[i], INPUT);
    }

    buttons_init();
    encoders_init();
    usart_init(115200);
    delay(20);
    Serial0.println("a3-motion ready");

    strip.begin();
    show_within_budget(strip);
}

void loop() {
    static uint32_t nextInputScanUs = 0;

    uint32_t nowUs = micros();
    if ((int32_t)(nowUs - nextInputScanUs) >= 0) {
        // Scan inputs at a fixed cadence to keep MUX work predictable.
        buttons_update();
        encoders_update();
        nextInputScanUs = nowUs + INPUT_SCAN_INTERVAL_US;

        // Easter egg: BUTTON_00 + BUTTON_09 held simultaneously.
        if (readMuxDigital(BUTTON_00) == LOW && readMuxDigital(BUTTON_09) == LOW) {
            runA3Special(strip, BUTTON_00, BUTTON_09);
            return;
        }
    }

    // Drain several queued commands per loop without starving input scans.
    uint32_t cmdStartUs = micros();
    while ((uint32_t)(micros() - cmdStartUs) < CMD_PROCESS_BUDGET_US) {
        uint8_t cmdByte;
        if (!usart_readByte(&cmdByte)) {
            break;
        }
        protocol_process(cmdByte);
    }

    protocol_led_flush();
}

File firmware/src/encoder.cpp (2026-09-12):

#include "encoder.h"
#include "mux_io.h"
#include "multiplexer_map.h"
#include <Bounce2.h>

static int16_t encoderDeltas[ENCODER_COUNT];
static int16_t encoderRemainder[ENCODER_COUNT];
static uint8_t lastEncoderState[ENCODER_COUNT]; // (A<<1)|B
static int8_t lastMoveDir[ENCODER_COUNT];

static Bounce  switchBouncers[ENCODER_COUNT];
static bool    switchSawRise[ENCODER_COUNT];
static bool    switchSawFall[ENCODER_COUNT];

// Quadrature decode table.
// Index = (prevState << 2) | newState, state bits: bit1=A, bit0=B.
static const int8_t QEM[16] = {
     0, -1,  1,  0,
     1,  0,  0, -1,
    -1,  0,  0,  1,
     0,  1, -1,  0
};

void encoders_init() {
    for (uint8_t i = 0; i < ENCODER_COUNT; i++) {
        encoderDeltas[i] = 0;
        encoderRemainder[i] = 0;
        lastMoveDir[i] = 0;
        switchSawRise[i] = false;
        switchSawFall[i] = false;

        // Capture initial A/B state for quadrature
        selectMuxChannel(ENCODERS[i].gpioB.muxIndex);
        int a = (digitalRead(ENCODERS[i].gpioA)      == HIGH) ? 1 : 0;
        int b = (digitalRead(ENCODERS[i].gpioB.gpio) == HIGH) ? 1 : 0;
        lastEncoderState[i] = (uint8_t)((a << 1) | b);

        // Attach switch bouncer with the correct MUX channel already active
        // so that the initial state read by attach() is accurate.
        selectMuxChannel(ENCODERS[i].switchInput.muxIndex);
        switchBouncers[i].attach(ENCODERS[i].switchInput.gpio, INPUT_PULLUP);
        switchBouncers[i].interval(5);
    }
}

void encoders_update() {
    for (uint8_t i = 0; i < ENCODER_COUNT; i++) {
        // --- Quadrature decode (A direct GPIO, B via MUX) ---
        selectMuxChannel(ENCODERS[i].gpioB.muxIndex);
        int a = (digitalRead(ENCODERS[i].gpioA)      == HIGH) ? 1 : 0;
        int b = (digitalRead(ENCODERS[i].gpioB.gpio) == HIGH) ? 1 : 0;
        uint8_t newState = (uint8_t)((a << 1) | b);
        uint8_t prevState = lastEncoderState[i];
        int8_t delta = QEM[(prevState << 2) | newState];

        // Recover occasional skipped intermediate quadrature state caused by
        // multiplexed sampling (two-bit jump: 00<->11 or 01<->10).
        if (delta == 0 && newState != prevState) {
            bool oppositeJump = ((prevState ^ newState) == 0x03u);
            if (oppositeJump && lastMoveDir[i] != 0) {
                delta = (int8_t)(2 * lastMoveDir[i]);
            }
        }

        if (delta > 0) {
            lastMoveDir[i] = 1;
        } else if (delta < 0) {
            lastMoveDir[i] = -1;
        }

        encoderDeltas[i] += delta;
        lastEncoderState[i] = newState;

        // --- Switch debounce (switch is MUX-based) ---
        selectMuxChannel(ENCODERS[i].switchInput.muxIndex);
        switchBouncers[i].update();
        if (switchBouncers[i].rose()) switchSawRise[i] = true;
        if (switchBouncers[i].fell()) switchSawFall[i] = true;
    }
}

void encoders_readAndClear(int16_t *deltas, uint8_t *switchStates, uint8_t count) {
    for (uint8_t i = 0; i < count && i < ENCODER_COUNT; i++) {
        int16_t raw = encoderDeltas[i] + encoderRemainder[i];
        int16_t step = raw / ENCODER_COUNTS_PER_DETENT;

        // Fast turns on a multiplexed B channel can occasionally miss one of
        // the 4 transitions belonging to a mechanical detent. If we saw at
        // least (N-1) transitions in one direction, count it as one detent.
        if (step == 0) {
            int16_t absRaw = (raw < 0) ? (int16_t)(-raw) : raw;
            if (absRaw >= (int16_t)(ENCODER_COUNTS_PER_DETENT - 1) && absRaw > 0) {
                step = (raw > 0) ? 1 : -1;
            }
        }

        encoderRemainder[i] = raw - (step * ENCODER_COUNTS_PER_DETENT);

        deltas[i]        = step;
        encoderDeltas[i] = 0;

        uint8_t bit0 = switchBouncers[i].read() ? 1 : 0;
        uint8_t bit1 = (switchSawRise[i] && switchSawFall[i]) ? 1 : 0;
        switchStates[i]  = (bit1 << 1) | bit0;

        switchSawRise[i] = false;
        switchSawFall[i] = false;
    }
}

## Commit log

2023-05-11 migrate v2 motion controller to new repository
    [a3motion_buttonmatrix_v01.kicad_pcb, a3motion_buttonmatrix_v01.kicad_sch, a3motion_mainboard_v01.kicad_pcb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]
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2023-07-27 fix system button pins and pullup
    [main.cpp]
2023-07-27 fix encoders, send increment only
    [main.cpp]
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2023-08-08 invert low/high for rec/shift/tap buttons
    [main.cpp]
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2023-08-29 consolidate/fix receiving of LEDs via serial
    [main.cpp]
2023-10-02 add freeCAD design
    [a3motion_design.FCStd]
2023-10-04 cleaned freecad > technical drawing
    [a3motion_design.FCStd, a3motion_design_technical_drawing.FCStd]
2023-10-08 button matrix
    [a3motion_mainboard_v01.kicad_pcb, a3motion_mainboard_v01.kicad_sch, button_arr.kicad_sch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]
2023-10-08 freecad next to kicad
    [a3motion_design_technical_drawing.FCStd, button_arr.kicad_sch, button_matrix.kicad_sch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]
2023-10-08 pcb in freecad aligned
    [a3motion_design_technical_drawing_neu.FCStd]
2023-10-08 top encoder und zechdraw
    [a3motion_design_technical_drawing_neu.FCStd, button_arr.kicad_sch, button_matrix.kicad_sch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]
2023-10-08 align top encoder
    [pcb_top.kicad_pcb]
2023-10-08 rubberpad draft
    [a3motion_design_technical_drawing_first_drafts.FCStd, a3motion_design_technical_drawing_neu.FCStd, a3motion_design_technical_drawing_rubberpad.FCStd]
2023-10-08 Version update
    [button_matrix.kicad_sch, button_matrix_round.kicad_sch, enc_arr.kicad_sch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]
2023-10-08 pcb cut off
    [button_matrix.kicad_sch, button_matrix_round.kicad_sch, enc_arr.kicad_sch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]
2023-10-08 good progress
    [a3motion_design_technical_drawing.FCStd, a3motion_design_technical_drawing_first_drafts.FCStd, a3motion_design_technical_drawing_rubberpad.FCStd]
2023-10-08 update to 74hc4053aft
    [button_matrix.kicad_sch, v3.1.kicad_pcb]
2024-01-14 cleanup repo
    [a3motion_3d.FCStd, a3motion_buttonmatrix_v01.kicad_pcb, a3motion_buttonmatrix_v01.kicad_sch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]
2024-01-15 started placement
    [v3.1.kicad_pcb, v3.1.kicad_sch]
2024-02-11 pcb main fertig
    [button_matrix.kicad_sch, button_matrix_round.kicad_sch, enc_arr.kicad_sch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]
2024-03-27 just a commit to reassemble changes of the past month
    [v3.1.kicad_pcb]
2024-04-04 finished top and main PCB
    [encoder_matrix.kicad_sch, freerouting.dsn, led_arr2.kicad_sch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]
2024-04-06 generated gerber files v31
    [BOM.ods, bom.csv, bom_rpi.csv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]
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2025-09-25 changed workplace
    [v3.1.kicad_sch]
2025-09-25 changed workplace2
    [v3.1.kicad_sch]
2025-09-25 change workplace3
    [v3.1.kicad_sch]
2026-02-13 before ki
    [button_matrix.kicad_sch, button_matrix_round.kicad_sch, enc_arr.kicad_sch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]
2026-02-25 clean up
    [BOM.ods, bom.csv, bom_rpi.csv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]
2026-02-25 clean up merge sym libs
    [BOM.ods, bom.csv, button_arr.kicad_sch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]
2026-02-26 new case layout
    [a3_motion_new.FCStd]
2026-03-01 finished schematic
    [bom.csv, button_arr.kicad_sch, button_matrix.kicad_sch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]
2026-03-01 cleanup led driver
    [led_driver.kicad_sch, motion_pcb.kicad_sch]
2026-03-01 add pcb makro and freecad pcb design
    [a3_motion_new_ra.FCStd]
2026-03-01 created submodule for enc pot mix
    [enc_pot.kicad_pcb, enc_pot.kicad_sch, motion_pcb.kicad_sch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]
2026-03-04 new layout mx
    [a3motion.FCStd]
2026-03-04 more space
    [a3motion.FCStd]
2026-03-04 add hands
    [a3motion.FCStd]
2026-03-05 changing labels
    [enc_pot.kicad_pcb, enc_pot.kicad_sch, led_arr2.kicad_sch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]
2026-03-07 finished pcb motion.
    [enc_pot.kicad_sch, led_arr2.kicad_sch, led_driver.kicad_sch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]
2026-03-07 finished design
    [enc_pot.kicad_sch, led_arr2.kicad_sch, led_but.kicad_sch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]
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2026-05-16 easter egg hoffentlich klappt das
    [motion_pcb.kicad_pcb]
2026-05-19 Flex Firnmware rocks git add -A!
    [config.h, main.cpp]
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2026-08-25 intel nuc as core inhouse
    [a3_motion_new.FCStd, a3_motion_new_ra.FCStd, a3motion.FCStd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]
2026-08-26 add productionfiles
    [housing_v3-motion_box.3mf, housing_v3-motion_pcbCut008.stl, housing_v3-motion_pcbfaceplate.3mf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]
2026-09-24 docs: the README opens with the repository's name
    It opened on "# Setting up a new installation" -- a section heading standing
    in for a title, so the public landing page began mid-thought and never said
    what the repository is. The two real top-level headings move down one level;
    the "# Example static IP configuration:" line is a comment inside a code
    block and is left exactly as it was.
2026-09-24 docs: name the board the device runs on
    The setup section described flashing "Raspian" onto an unnamed Raspberry Pi
    and set the hostname to a3-motion-v02 -- instructions written for a hardware
    revision two behind the current one. The device runs on a Raspberry Pi 5.
    Fixes the OS name with it: the distribution has been Raspberry Pi OS for
    years, and "Raspian" was never its spelling either.
2026-09-26 feat(firmware): keep the key LEDs within a current budget
    The 44 WS2812B under the keys hang on the USB 5 V and nothing limited
    them: full white is about 2.6 A from a 0.5 A port, and the failure is a
    brown-out, not a dim panel. Every show now goes through
    show_within_budget(), which estimates the draw (led_budget.h, datasheet
    figures) and, only when it is over LED_BUDGET_MA, dims all pixels by one
    factor for that show -- the buffer keeps the asked-for colours, so
    dimming never compounds.
    Host tests: `pio test -e native` (new env, Unity). LED_BUDGET_MA is
    provisional until measured on the rig. Part of a3-motion-ui#21.
    [config.h, main.cpp, protocol.cpp]
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2026-10-03 feat: host.py --pcb-test for a freshly built board
    Every button press toggles its own LED, any encoder click turns the colour of
    every lit LED one step round the wheel; what moves is printed as before. A
    dark LED, a wrong colour or a dead encoder shows at once.
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2026-10-04 fix(firmware): find the panel by its USB ID, not by a tty number
    The panel is /dev/ttyACM0 on one machine and ttyACM1 on the next, so a
    port in platformio.ini was wrong somewhere and carried a hand patch.
    The board file now names the CH343 bridge (1A86:55D3) the firmware talks
    through on UART0, instead of the ESP32's native USB (303A:1001), which
    the panel does not use. PlatformIO finds the upload and monitor port by
    it, so platformio.ini names no port.
    host.py reads the same entry: one matching port is taken, of several the
    one answering PING, none is an error naming the USB ID. Tests in
    test_host.py (python3 -m unittest test_host).
    [host.py]
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2026-10-04 feat(housing): a v3 housing that prints on the A1 and holds what goes in it
    housing_v3_neu is rebuilt from sketches and Part features only, every
    sketch on the global canvas, repeats as links. The old file had solids
    without sketches and extrusions whose profile was gone.
    - Walls 7 mm at the sides, 6 mm front and back; the faceplate lip sits
    in a 3.6 mm rebate. Every part is at most 238 x 252 mm.
    - Both joints are 45 degree scarfs, so neither half prints a floating
    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
    [housing_v3-motion_box.3mf, housing_v3-motion_display_clamp.stl, housing_v3-motion_enclosure_bottom.stl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]
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2026-10-04 chore(housing): the rebuilt v3 is housing_v3, the old model and the backups go
    housing_v3_neu.FCStd replaces housing_v3.FCStd under its name; the
    pre-rebuild copy and the August .FCBak are in the history.
    [housing_v3.FCStd, housing_v3_neu.FCStd, housing_v3_neu.before-rebuild.FCStd]
2026-10-06 chore: ui to 9a04236, a mouse event can no longer take a finger's blob
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2026-10-16 fix(firmware): a clockwise detent counts up
    Every encoder counted down clockwise (device check 2026-10-16, on every
    page). The decode table moves to encoder_decode.h so a native test can pin
    the direction, and its sign is flipped.
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2026-10-16 fix(firmware): the pots follow the hand, not the host's poll
    The pot filter (EMA of a quarter per step, then a deadband) only stepped when
    the host sent GET_POTS. host.py asks every cycle; the UI asks every fifth,
    about every 25 ms, so a move needed ~8 asks (~200 ms) for 90 % and ~24
    (~600 ms) to land. The filter now runs on the input scan, one pot per scan
    (every ~1.8 ms per pot), and GET_POTS only reads it: 90 % in ~15 ms, landed
    in ~45 ms, however often the host asks.
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2026-10-30 chore: pin ui (copyright holder, zombie fix)
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
